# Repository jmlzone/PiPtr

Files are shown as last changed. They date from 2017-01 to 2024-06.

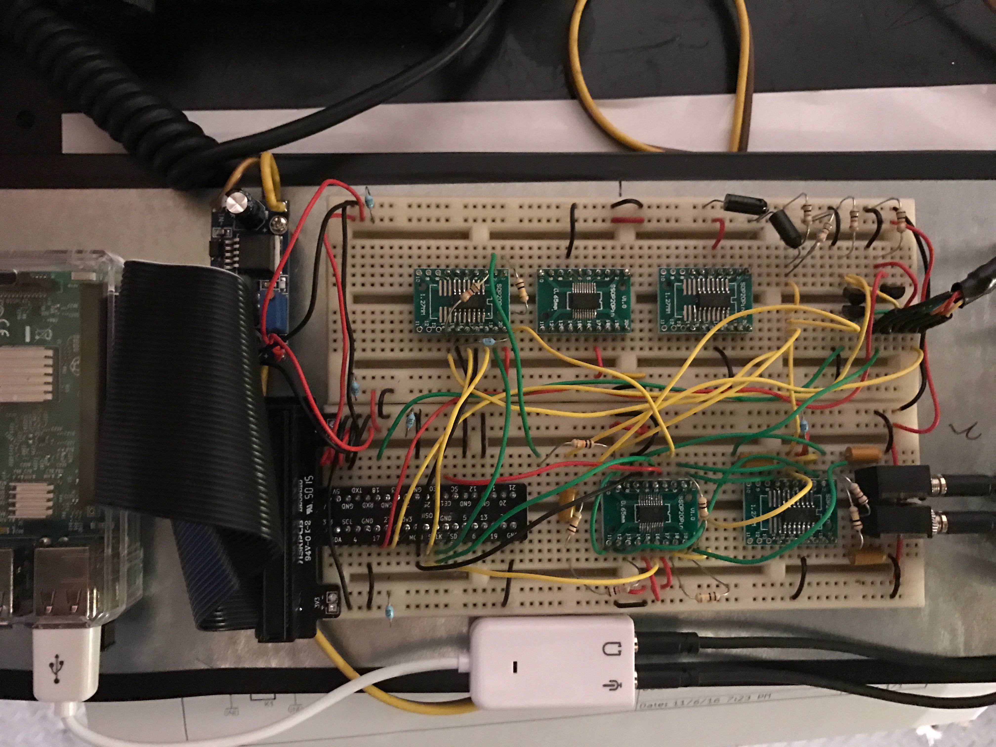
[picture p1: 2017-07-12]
doc/IMG_1390.jpg

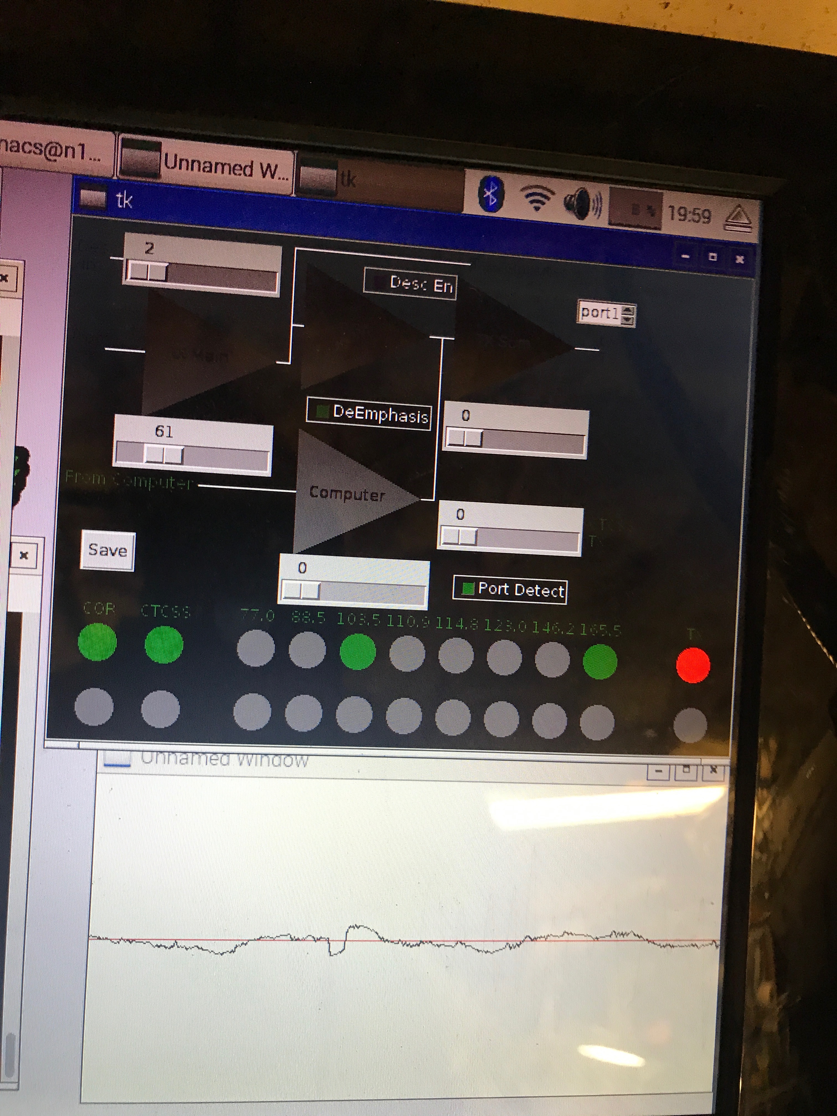
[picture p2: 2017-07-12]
doc/IMG_1817.jpg

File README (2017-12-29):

This is the README for the Rasberry Pi Ham Hadio Repeater Controller
project.  The Goal of this project is to develop an inexpensive
linking repeater controller witha cost of aproximatly $100/port vs
current commerical solutions which are closer to $160/port.

This is an extensable linkable controller with both local and remote
linking.

For information on the mmra network see mmra.org
For information on this project contact jml@jmlzone.com.

For information on setting up this project on a Pi3 please see the Quickstart.txt

Most of the code will be in Python, however some of it is in C.

Eventually there will be good documeation and a bug/enhancement
tracking WIKI or some such thing.

Current state: The test repeater is stable on the air but many many
things are still to be done.

----------------------------------------------------------------------
Mailing lists for the project
  Please join one or more of the groups below.
MMRA-PiPtr-Hardware+subscribe@groups.io
MMRA-PiPtr-Software+subscribe@groups.io
MMRA-PiPtr-Documentation+subscribe@groups.io

----------------------------------------------------------------------

As you know the MMRA maintains a network of 22 repeaters.  A repeater
is basically a receiver, a transmitter and a controller
in-between. While the network generally works, there are some upgrades
we are continually working on.  One of these efforts being led by me,
James N1DDK, is developing a new repeater controller to enhance the
remote controllability, monitoring and adjusting of the
repeaters. Most of the repeater controller in use today are based on
designs over 20 years old. There have been many advances in technology
in the past 20 years. This project is bringing a more modern, more
scalable and more software based and controllable approach based on
mostly standard hardware and using popular modern methods.

 There are some guiding principles to this project:
1) No Jumpers, switches or mechanical pots that can be set incorectly at a site needing a return visit.
2) Open source -- its part of the Ham culture to experiment and share. This will also ensure longevity of the project beyond the initial developers.
3) Better ease of use than similar commercial products.
4) Scaleability and cost per port more effective than the commercial products.
5) Mostly software for simple functions like CTCSS encode / decode, DTMF encode / decode, timers, morse etc.
6) Well documented

Goals
 * Ease of use for users and control operators.
 * Web back end to view status and control linking.
 * Ability to sell hardware as a fundraiser for MMRA.

To this end I have been working mostly solo with some input from K1IW and W1BRI (and some non members) and I have a working prototype on the air on 224.080 as part of a test platform. The next goals will be to make some boards and have further testing and development.

Here is a list of some of the help that is desired:
 * Programming help in C and Python (possibly java/java script for some of the web interface)
 * Schematics design/review for the custom audio board.
 * Documentation help -- there is some basic documentation, but it would be good to have much more on both hardware, software and user guides.
 * Mechanical/sheet metal design for an enclosure, etc
 * Building help, both mechanical and building the initial boards for testing.
 * Testing help using the controller on a bench and trying things before we put them on the air.
 * On the air testing.

Want to learn more?
 There is a git-hub repository for the software, documentation and issue tracking:
https://github.com/jmlzone/PiPtr
There may be a talk about the project at Boxborough!

Even if you don't know anything about software or repeater controllers you can still help! You don't need to know anything to be a documentation volunteer!

Ready to help?
Contact James, n1ddk@mmra.org.

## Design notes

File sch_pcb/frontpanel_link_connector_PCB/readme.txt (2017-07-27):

This directory contains the schematic and PCB for the front panel connector board.  This will be used at the leftmost and rightmost 
boards in a rack chassis to allow interconnecting between chasses

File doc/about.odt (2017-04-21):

PiPtr Documentation.

Rev 0.0 April 14, 2017

James Lee N1DDK

Revision | Date | Who | Description
0.0 | April 14,2017 | James Lee | Initial document

Notes:

Table of Contents

# Introduction

This repeater control project is more than yet another open source ham radio repeater cotroller.

Take a moment to read at least th enext few paragraphs before diving into and of the latter detailed sections.

Also donations are welcome through PayPal to jml@jmlzone.com or through mmra.org.

## Why?

The Minute Man repeater Association (www.mmra.org) maintains a network of over 20 repeaters throughout eastern and metro west Massachusetts. These repeaters are controlled by a variety of different controllers with obscure programming and control methods. While the technical committee for these repeaters has tried to minting a constant model, very few control operators are able to easily configure and maintain the system. When using commercial repeater controllers, the controllers tend to be over $150 per port and have limited expansion capabilities for large sites or are over kill with more ports than needed for a remote site.

Other issues seen on the MMRA network are:

- Difficulties with clock synchronization on the controllers on the network.
- Occasional random behavior from aging EEPROMs, lighting struck hardware and other controller hardware flakiness.
- Lack of source control and documentation for the repeater programming.
- long lag times when network comes up due to cascaded slow controller response.
- Limited internet control

## Goals

- Open source hardware and software for long term wide spread support.
- Cost effective goal of $50 per port.
- Fast and flexible networking
- Extensive internet and non internet control
- Accurate clocks
- Software upgradable.

## Why not?

Why not use open repeater or some of the other open source projects out there?

- The may not be as “open” as the name suggests.
- The may not be designed for linking and some of our other goals.

## Basic Architecture

The basic design is a add on board for a Raspberry Pi 2, 3 or beyond with minimal hardware to provide a full high end repeater controller.

Schematics will be captured in eagle.

Software in Python and C primarily. The 2 most common current programming languages.

There are 2 radio ports per controller and the controllers have side cascading ports to build up in groups of 2. See example network topologies later in the document a site with 7 repeaters, a remote base and 2 link radios would be configured with 5 of these controllers and all linking combinations are possible!

### Custom Hardware

The custom hardware consists of the radio interface and the audio path. It include environmental monitoring to see if you left the lights on in the shelter or if the temperature or humidity is out of bounds. Built in measuring of the 12v repeater power supply and several available user analog channels.

The main rule of thumb is zero jumper and zero mechanical potentiometers. All adjustments are made via software controllable elements.

### Audio

Audio is routed in and out of the computer via standard inexpensive USB sound cards.

- There is an analog audio path for a repeater to stand alone.
- There is an analog audio path for the 2 repeaters on a controller to link.
- There are 2 analog audio paths for controller to controller linking.
- Additionally since the audio goes in and out of the computer, it is possible to do digital audio formats and or digital repeater linking all in software. This is TBD and currently beyond the scope of the base project.

### Digital Audio Functions

Base digital audio decoding functions include:

- Touch tone decoding
- Soft CTCSS decoding

Basic Audio sending functions include:

- Morse generation
  - ASCII to morse
  - Any tone frequency (specified in Hertz)
  - Any speed (specified in Words per minute)
  - Any amplitude (specified in arbitrary volume units)
- Tone generation
  - Any simple tone or sequence of tones
  - Specified as groups of three numbers:
    - Tone in Hertz
    - Duration in mili-Seconds
    - Amplitude
  - Delays between beeps are just tones of zero amplitude
- Speech Generation
  - Text to speech using one available open source programs
- Wave file play back

Soft modem capabilities allow nodes at remote sites to form an ad-hoc data network a link radio to allow remote controlling, updating and time synchronization.

## Example Network Topologies

### A Basic Node

The basic topology of a single repeater node is 2 radio ports.

The radio ports may be either full duplex repeaters or link/remote base radios.

There are also 2 link ports to link to other controllers.

Controller link1 link2 Radio 1 Radio 2 Drawing 1: Basic Node

### A Single Repeater

A single repeater is the simplest configuration. The repeater would be connected to radio port 1 or 2. thats all.

Controller Repeater

Drawing 2: A single repeater configuration

### 2 Repeaters

With 2 repeaters a repeater would be connected to each radio port. By default they will be independent

repeaters; however the repeaters are completely independently controllable or easily linkable.

Repeater 1 Repeater 2 Controller

Drawing 3: 2 repeater configuration

### A Repeater and a link radio (or remote base)

A link or remote base is connected similarly to a repeater, except it is used half duplex and tail hangs and messaging on the link or remote base radio is minimized.

Controller Repeater Link Radio

Drawing 4: Single repeater with link

### 2 Repeaters With 2 Link Radios

In this configuration it is possible to group a repeater and link on a single controller like above, or you could put both repeaters on once controller and both link radios on the second controller. In the recommended configuration shown below, the controllers would be configured as follows:

- On the repeater controller
  - Both radio ports configured as repeaters
  - The repeaters can be cross linked by connecting both to link 1, the internal link.
  - Either (or both) repeater can be connected to link 2 or link 3 to use the link radios
- On the link radio controller
  - Both ports configured as Links
  - Link radio 1 configured to link 2
  - Link radio 2 configured to link 1

Controller 2 Controller 1 Repeater 1 Repeater 2 Link Radio 2 Link Radio 1 Link 2 Link 3

Drawing 5: 2 repeaters, 2 controllers and 2 links

### More

The examples shown in this section are just examples. You can have as many controllers connected to each other as you like. Also it is not required to connect all link2’s to link2’s and link 3’s to link 3’s so you can have additional logs and global links as makes sense for your network.

Controller 1 Controller 2

Link Radio 1 Link Radio 2 Repeater 1 Repeater 2 Repeater 3 Repeater 4 Link 2 Link 2 Link 3 Link 3Drawing 6: A bigger configuragtion

Controller n

Remember:

- All radio ports can act as fully independent repeaters.
- Link 1 exists to allow the 2 ports on a controller to link.
- Link 2 and Link 3 are simple connections to physically co-located radios and repeaters.

# Hardware Description

## Radio Port

The radio port comes out on a 10 pin header (only 9 pins are used). This may be cabled with a simple ribbon cable to a 9 pin D connector DE9F to be compatible with radios bailed for an Scom 7330 controller. However there is more capability than a basic Scom controller.

Header Pin | De 9 pin | Function
1 | 1 | Receiver audio
2 | 6 | GND (RX audio)
3 | 2 | COR (logic)
4 | 7 | GND (CTCSS audio)
5 | 3 | CTCSS decode (logic / or discriminator audio)
6 | 8 | Transmitter (CTCSS audio or logic control)
7 | 4 | PTT
8 | 9 | GND (Transmit Audio)
9 | 5 | Transmitter audio
10 | NA | Physical key

### Receiver Logic Connections

The COR and CTCSS inputs can be logic level from 1.6V to 30V for a logic ‘1’ and less than 0.6V for a logic ‘0’ The polarity of the logic does not matter since it can be inverted in the configuration. There are no jumpers to set. If they are not used, the pins can be left un-connected.

### CTCSS

If a hardware CTCSS decoder is not part of the radio hardware it is not needed. Discriminator audio may be brought in on the CTCSS pin or of the receiver does not high pass the audio to filter out the CTCSS tones, the CTCSS Tones will be decoded off the receive audio.

### DTMF

The DTMF tone will be decoded off the discriminator or receive audio, which every was used for the CTCSS.

## Transmitter Connections

### PTT

The push to talk output is an open drain control camaple of sinking 200mA at up to 35 volts.

### CTCSS

The CTCSS output can be either an open drain output or an audio output under software contol.

## Environmental Monitor

The environmental monitor consists of a DHT22 (AM2302) temperature and relative humidity sensor and a light depending resistor (CDS cell). These are both mounted to the board and are monitored periodically by the software.

## User IO

The user IO convicts of TBD logic IO pins and TBD analog input pins. The digital pins can be configured for input or output. The analog pins are by default scaled for 0-25 volts

## Host Port

The host port is the mapping from physical bus pins on the host board to the functions used on the controller.

PI pin assignments
pin # | Pi Name | Pi Alt | function | Note:
1 | 3.3v
2 | 5v
3 | GPIO2 | SDA1
4 | 5v
5 | GPIO3 | SCL1
6 | gnd
7 | GPIO4 | GPIO_GCLK
8 | GPIO14 | TDX0 | dctcss1
9 | gnd
10 | GPIO15 | RXD0 | dctcss2
11 | GPIO17 | GPIO_GEN0 | cor1
12 | GPIO18 | GPIO_GEN1 | pwm0 | Was Ptt earlier
13 | GPIO27 | GPIO_GEN2 | hwctcss1
14 | gnd
15 | GPIO22 | GPIO_GEN3 | ptt1
16 | GPIO23 | GPIO_GEN4 | COR2
17 | 3.3v
18 | GPIO23 | GPIO_GEN5 | CTCSS2
19 | GP10 | SPI_MOSI
20 | gnd
21 | GPIO9 | SPI_MISO
22 | GPIO25 | GPIO_GEN6 | ptt2
23 | GPIO11 | SPI_SCLK
24 | GPIO8 | SPI_CE0_N | SPIG2A
25 | gnd
26 | GPIO7 | SPI_CE1_N | SPIG1
27 | ID_SD
28 | ID_SC
29 | GPIO5 | | SPIA
30 | gnd
31 | GPIO6 | | SPIB
32 | GPIO12 | | SPIC
33 | GPIO13 | | LINK1O
34 | gnd
35 | GPIO19 | | pwm1
36 | GPIO16 | | LINK1C
37 | GPIO37 | | liknc2o
38 | GPIO20 | | link2c
39 | gnd
40 | GPIO21

## I2C bus

There is a 3.3v and 5v shared I2C bus available for expansion such as extra GPIO or specific control functions. The 5V I2C is used on the board for slave addresses: so be careful when adding I2C devices.

## Audio Path Theory of Operation

The incoming audio from the receiver is gained up to be 2V peak to peak coming out of the input buffer. When the main audio is used to drive the soft CTCSS and DTMF decoder, there is a fixed attenuation before this level goes out to the computer, This path can be enabled for initial tune up. Software can be used to monitor this point and help adjust the base receiver level.

From the first level receiver input amplifier the signal level is adjustable to any of the 4 link / mixing busses:

- Link 0, local transmitter only.
- Link 1, either transmitter on this node.
- Link 2, an external link
- Link 3, an external link

The link connection and level are controllable via the software controllable potentiometers. Remember that these soft pots also contain switches and the connection to any of these points is disconnected when not in use.

From the link / mixing busses the signal can be picked up by the programmable gain amplifier which has the ability to select any of the 4 sources as its input. If needed gain can be applied here. This output is then mixed with the sound card output buffer before being sent to the transmitter.

From the USB sound card a programmable gain buffer is used to buffer the sound card output to a fixed impedance. This is then mixed with the receive audio from the programmable gain amplifier above.

The transmit audio is a programmable gain buffer which gets the sum of the selected receive audio and the sound card audio.

When discriminator output is used to drive the CTCSS decoder the buffer from eh CTCSS input is buffered to 2V peak to peak and then attenuated before going out to the USB sound card to be used for the soft CTCSS and DTMF decoding.

All the audio circuits are reference to Vref at 2.5 V and supplied from the 5V supply. The 5V analog supply is just a low pass filter version of the 5V supply bucked from 12V supply.

# Quick Start Guide

Since we are currently in “developer mode” it is highly recommended that you have a HDMI monitor and USB keyboard and mouse on your Raspberry Pi and to have your Raspberry Pi on the internet, hardwired or wireless with a high speed data connection for all the software you will install.

## Install Rasbian.

Jessie is what is being used for the initial bring up. Follow the directions one the raspberry pi web site to install the base operating system.

## Post configure your raspberry pi

Run raspi-config:

1. Set your host name to be unique; Suggestion callsign_frequency: ie n1ddk_224_080
2. Enable spi (under advanced options)
3. Strongly suggested to set your internationalization options, timezone, keyboard, etc.

## Update your Raspberry Pi

sudo aptget-update

sudo aptget-upgrade

## Install supplemental packages

sudo apt-get install -y python-dev

sudo apt-get install -y espeak

## Bring in the git repository for the repeater control software

git clone …

## give it a test spin

sudo python/main.py

# Software Description

## Configuration XML

The config.xml file contains a template and sample configuration for the controller. Although intended to be machine readable it is generally human readable. The Controller contains a GUI with limited capability to dump the file, however a full functioning editor for this file could be developed.

Once the host name four your RaspberryPi node is set, a node specific version of this file will be loaded (and saved) using the naming rules defined below.

## File Loading and Overriding

The Python and config files are by default in the python directory. Once your host name is set to something other then the default of ‘raspberrypi’ if a directory matching your host name exists files in that directory will have precedence over files in the python directory. Additionally the file <hostname>/<hostname>.xml (where <hostname> is replaced with your host name) will be the highest precedence configuration file and will be the file name used when saved from the GUI.

If you want to override any of the python files with your user code, you can copy the file from the python directory and edit it and place it in the <hostname> directory. However note that if you get an update to the code, it will not be reflected in your edited files.

## Primary C programs

These program reside in the bin directory; C source, headers and makefile are provided in the c directory. They are called and run directly from the main python code; however you can trunthem and test them form the command line if you wish to experiment with them.

### multimon

Multimon was written in 1996 by Thomas Sailer (sailer@ife.ee.ethz.ch, hb9jnx@hb9w.che.eu) and released with GNU general public license. It has been significantly enhanced by James Lee N1DDK in 2016 and 2017 to include ALSA input and CTCSS decoding. Additionally the DTMF decoding has been enhanced to decode larger windows for less glitching and a ‘mute’ output was added to the DTMF decoding.

Multimon includes the capability to decode many other formats such as bell202 for APRS, those capabilities exist within the program but are not currently used by the repeater controller.

### mout

mout is the Morse output routine based on ascii to morse code written by James Lee (KA1KUB in 1983) and ported to C in 2016 and added ALSA output in 2017 by James Lee N1DDK. This code take a command line of exactly 5 arguments:

mout <device> <wpm> <freq> <amplitude> <message>

i.e.:

mout sysdefault:CARD=Device 22 660 1000 "this is a test "

### tout

Tout is the general purpose tone generator. It take inputs in sets of 3 and generates one or more tones in a sequence.

tout <device> <freq> <amplitude> <duration> [<freq> <amplitude> <duration>...]

i.e.:

tout sysdefault:CARD=Device 660 1000 100

tout sysdefault:CARD=Device 660 1000 100 100 0 10 440 900 48

## System Executables

### aplay

Aplay is the ALSA play file utility used to play wave files. It is called (from the system) by the controller code when a wave file is needed to be played.

### espeak

Espeak which was one of the additional packages you needed to load is a text to speech routine which can be used in messaging and is used int he talking clock announcements.

## Python Files

### main.py

As the name describes this the the main entry and launch point for the code. It brings in the other files and instantiates the 2 repeater ports, 2 command queues the GUI and (TBD other network control ports)

Once all the objects are instantiated, it called “load XML” to read in the configuration file. Next it starts threads for the 2 ports and the 2 command processors and the GUI.

### radioPort.py

This file has the place holders for all the configurable items on each radio port. It defines the RX and TX classes and the radioPort class. The radioPort creates multiple timers and instantiates the RX and TX classes and the FSM for each port.

### rptfsm.py

This file is the state machine that controls the behavior of a repeater or link. it is separated from the radioPort file since it is likely to undergo significant enhancement.

### cmd.py

This file houses both the command look up table (touch tome codes) for both ports and the code that is executed when a command is entered. It is likely to be greatly enhanced, as well as customized by for each repeater.

# Repeater Control Flow

## state machines

## timers

## command flow

## queues

### Example of Queuable “messages”

### Altername Messages

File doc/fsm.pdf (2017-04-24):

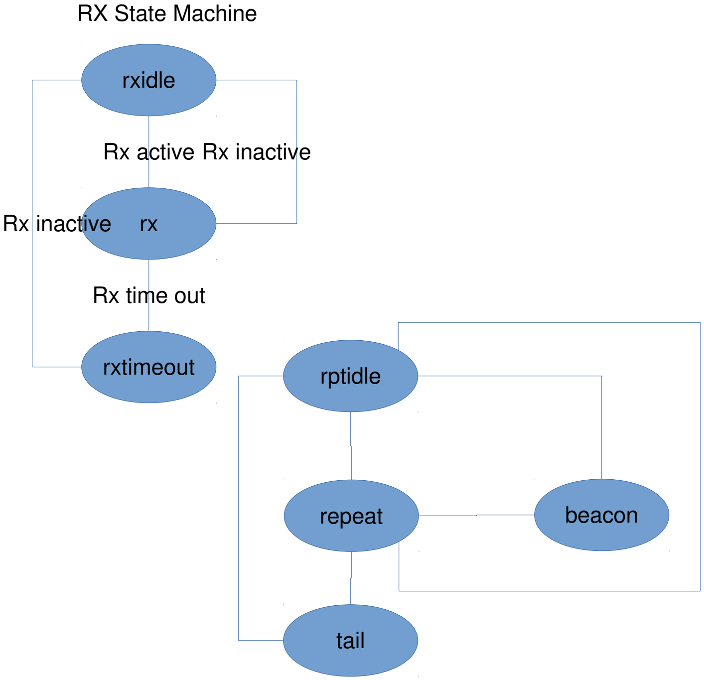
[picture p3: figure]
rxidle; rxtimeout; Rx active; Rx time out; Rx inactive; RX State Machine; rptidle; repeat; tail; beacon

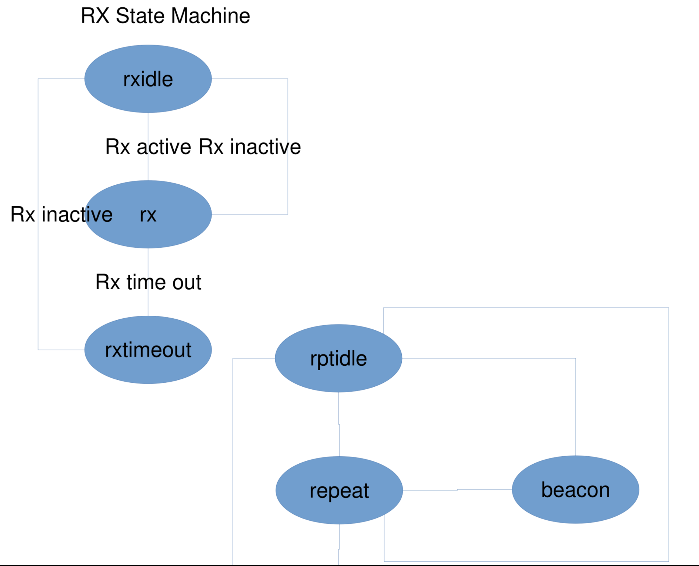
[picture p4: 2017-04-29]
doc/fsm.png

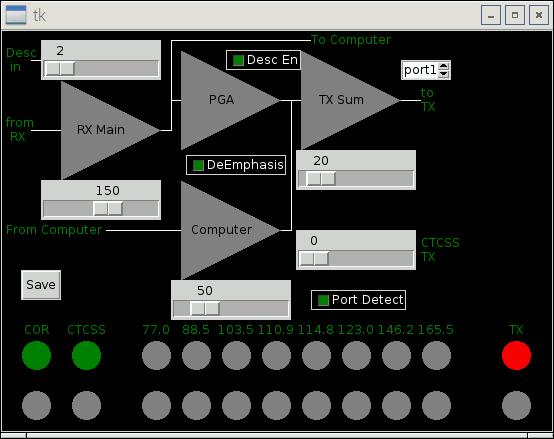
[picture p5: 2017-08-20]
doc/piptrgui.jpg

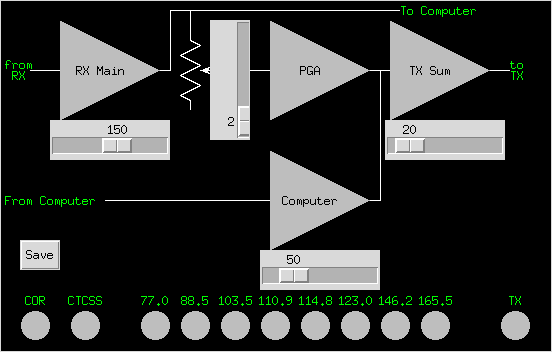
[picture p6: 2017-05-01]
web/ctrl_panel.png

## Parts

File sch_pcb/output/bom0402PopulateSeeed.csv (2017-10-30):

Designator | Manufacturer Part Number | Quantity
C212,C412 | CC0402KRX7R8BB392 | 2
C209,C210,C409,C410 | GRM155R71C273KA01D | 4
C107,C112,C111,C104,C101,C205,C222,C220,C207,C202,C215,C304,C306,C307,C303,C313,C310,C309,C314,C315,C316,C317,C318,C321,C320,C326,C405,C422,C420,C407,C402,C415,C504,C508,C502,C506,C521,C522,C530,C531,C543,C536 | 302010024 | 42
C102,C213,C203,C211,C219,C217,C226,C227,C228,C229,C230,C231,C413,C403,C411,C419,C417,C426,C427,C428,C429,C430,C431 | 302010012 | 23
C214,C223,C414,C423,C512,C510,C511,C509,C527,C528,C542,C541,C540 | 302010053 | 13
C319,C322,C323,C324,C325 | 302010178 | 5
C525,C526,C524,C523 | 302010027 | 4
C106,C103,C206,C201,C204,C225,C221,C208,C305,C312,C311,C308,C406,C401,C404,C425,C421,C408,C503,C507,C514,C520,C519,C518,C501,C505,C513,C517,C516,C515,C529,C532,C539,C534,C538,C537,C535,C533 | 302010019 | 38
J501 | 320010000 | 1
Q102,Q101,Q105,Q103,Q104,Q202,Q201,Q203,Q402,Q401,Q403 | 305030000 | 11
Q501 | 305030026 | 1
R504,R506,R503,R505,R507,R508,R519,R520 | 301010052 | 8
R118,R115,R207,R234,R211,R329,R330,R331,R407,R434,R411,R515,R516,R523 | RC0402FR-0733RL | 14
R124,R324 | 301010028 | 2
R235,R435 | RC0402JR-07680RL | 2
R108,R224,R210,R201,R205,R232,R228,R236,R237,R240,R327,R424,R410,R401,R405,R432,R428,R436,R437,R440 | 301010033 | 20
R112,R113,R109,R102,R101,R225,R206,R221,R222,R233,R229,R209,R227,R244,R301,R309,R323,R319,R318,R317,R316,R315,R425,R406,R421,R422,R433,R429,R409,R427,R444,R518 | 301010004 | 32
R214,R328,R414 | RC0402FR-0713K3L | 3
R509,R510,R511,R512,R501,R513,R517,R521,R522 | RC0402JR-0715KL | 9
R123,R103,R117,R213,R202,R203,R208,R230,R239,R238,R322,R302,R413,R402,R403,R408,R430,R439,R438 | 301010006 | 19
R514,R502 | 301010001 | 2
R223,R423 | RC0402JR-07200KL | 2
R106,R220,R231,R243,R241,R242,R420,R431,R443,R441,R442 | RC0402JR-0720KL | 11
R217,R417 | RC0402JR-0727KL | 2
R120,R104,R105,R110,R111,R107,R114,R212,R215,R219,R226,R308,R412,R415,R419,R426 | RC0402FR-072K2L | 16
R122,R116,R204,R404 | RC0402FR-073K3L | 4
R216,R218,R416,R418 | RC0402JR-0751KL | 4
R321,R310,R311,R312,R313,R314 | RC0402FR-0788K7L | 6
U104 | SN74HCT138DR | 1
U105,U111,U112,U110,U113 | SN74LV1T125DBVR | 5
U109,U206,U202,U203,U406,U402,U403 | SN74LVC1G3157DBVR | 7
U108,U204,U404 | 74LVC4066D,118 | 3
U502,U501,U505 | CM108B | 3
U102,U307,U308 | IP4234CZ6,125 | 3
U305 | MCP1700T-2502E/MB | 1
U504 | MCP1700T-3302E/MB | 1
U101,U208,U408 | MCP23008-E/SS | 3
U301 | MCP23017-E/SO | 1
U304 | MCP3008-I/SL | 1
U103,U107 | MCP4351-103E/ST | 2
U106,U201,U205,U401,U405 | MCP6004-I/SL | 5
U207,U407 | MCP6S26-I/SL | 2
U503 | TUSB2036VFR | 1
Y501 | ABLS-6.000MHZ-D-T | 1

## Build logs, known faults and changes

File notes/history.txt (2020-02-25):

    1  uptime
    2  ls /dev/usb
    3  ls /dev/usb/hiddev0 
    4  sudo reboot
    5  echo $AUDIODEV
    6  ls /dev/dsp
    7  aplay -1
    8  aplay -l
    9  ls /dev
   10  man aplay
   11  sudo apt-get update
   12  sudo apt-get upgrade
   13  sudo raspi-config
   14  exit
   15  which git
   16  pwd
   17  cd python
   18  ls
   19  git clone git://github.com/swharden/Python-GUI-examples
   20  ls
   21  cd Python-GUI-examples/
   22  ls
   23  cd 2016-07-37_qt_audio_monitor/
   24  ls
   25  python go.py 
   26  sudo apt-get install PyQt4
   27  hg clone https://www.riverbankcomputing.com/hg/sip
   28  which hg
   29  pip3 install SIP
   30  wget https://sourceforge.net/projects/pyqt/files/sip/sip-4.18.1/sip-4.18.1.tar.gz
   31  ls
   32  tar tfz sip-4.18.1.tar.gz 
   33  tar xfz sip-4.18.1.tar.gz
   34  cd sip-4.18.1/
   35  ls
   36  more README 
   37  python build.py prepare
   38  ls
   39  more README 
   40  ls
   41  more configure.py 
   42  python configure.py -help
   43  sudo python configure.py
   44  ls -ltr
   45  sudo make
   46  ls
   47  more Makefile 
   48  make 
   49  pwd
   50  cd ..
   51  wget http://sourceforge.net/projects/pyqt/files/PyQt4/PyQt-4.11.4/PyQt-x11-gpl-4.11.4.tar.gz
   52  ls
   53  ls PyQt-x11-gpl-4.11.4.tar.gz 
   54  tar tfz PyQt-x11-gpl-4.11.4.tar.gz 
   55  ls
   56  cd ../
   57  ls
   58  cd 2016-07-37_qt_audio_monitor/
   59  ls
   60  more ui_main.py 
   61  ls
   62  more SWHear.py 
   63  sudo apt-get install python-dev
   64  sudo apt-get install -y python-dev --fix-missing
   65  sudo apt-get update
   66  sudo apt-get install -y python-dev --fix-missing
   67  pwd
   68  ls
   69  cd sip-4.18.1/
   70  ls
   71  make
   72  make clean
   73  make
   74  sudo make installl
   75  sudo make install
   76  ls
   77  cd ../
   78  ls
   79  tar xfz PyQt-x11-gpl-4.11.4.tar.gz 
   80  cd PyQt-x11-gpl-4.11.4
   81  ls
   82  more README 
   83  python configure-ng.py
   84  sudo apt-get install qt
   85  sudo apt-get install qt4-dev-tools
   86  python configure-ng.py
   87  history
   88  ls
   89  more README 
   90  make 
   91  sudo make install
   92  ls
   93  cd ../
   94  ls
   95  python go.py 
   96  history
   97  python go.py 
   98  git clone https://github.com/pyqtgraph/pyqtgraph
   99  ls
  100  cd pyqtgraph/
  101  ls
  102  python setup.py
  103  python setup.py -help
  104  python setup.py --help
  105  python setup.py build
  106  sudo python setup.py install
  107  cd ../
  108  ls
  109  python go.py
  110  hi
  111  history
  112  python go.py
  113  git clone http://people.csail.mit.edu/hubert/git/pyaudio.git
  114  cd pyaudio/
  115  ls
  116  sudo apt-get install python-pyaudio
  117  python go.py
  118  pwd
  119  cd ../
  120  python go.py
  121  history
  122  sudo apt-get install python-matlibplot
  123  sudo apt-get install matlibplot
  124  sudo apt-get install matplotlib
  125  sudo apt-get install python-matplotlib
  126  python go.py
  127  sudo apt-get install python-scipy
  128  python go.py
  129  xterm &
  130  emacs 
  131  cd c
  132  ls
  133  cd multimon/
  134  ls
  135  ./bin-armv7l/multimon 
  136  ./bin-armv7l/multimon scope
  137  ls
  138  more unixinput.c 
  139  ls
  140  more demod_afsk12.c 
  141  ls
  142  more demod_dtmf.c 
  143  ls
  144  more mkcostab.c 
  145  ls
  146  ls bin-armv7l/mkcostab
  147  bin-armv7l/mkcostab
  148  ls -ltr
  149  more costab.c
  150  more costabf.c 
  151  more costabi.c 
  152  ls
  153  emacs Makefile
  154  bg
  155  ls
  156  more gen.c 
  157  ls
  158  more xdisplay.c 
  159  ls
  160  more multimon.h 
  161  cd python
  162  ls
  163  cd Python-GUI-examples/
  164  ls
  165  cd 2016-07-37_qt_audio_monitor/
  166  puthon go.py 
  167  python go.py 
  168  pwd
  169  cd python
  170  ls
  171  pwd
  172  ls
  173  ls ../
  174  mv ../gistfile1.py .
  175  more .
  176  more gistfile1.py 
  177  which python
  178  python gistfile1.py 
  179  python my_goertzel.py 
  180  python
  181  cd pythin
  182  cd python
  183  ls
  184  mroe my_goertzel.py 
  185  more my_goertzel.py 
  186  python my_goertzel.py
  187  ls ~/.ssh
  188  mkdir ~/.ssh
  189  ifconfig | more
  190  ls -l ~/.ssh
  191  python my_goertzel.py
  192  python setup.py build_ext -- inplace
  193  python setup.py build_ext --inplace
  194  pip instal Cython
  195  sudo pip install Cython
  196  python setup.py build_ext --inplace
  197  ls -ltr
  198  python my_goertzel.py
  199  cd ../
  200  mkdir c
  201  cd d
  202  cd c
  203  ls
  204  cc -o alsa_listen alsa_listen.c
  205  ls /usr/lib/alsa
  206  ls /usr/lib
  207  sudo apt-get install libasound2-dev
  208  sudo apt-get -y install libasound2-dev
  209  cc -o alsa_listen alsa_listen.c
  210  cc -o alsa_listen alsa_listen.c -lasound
  211  ls
  212  ./alsa_listen 
  213  which xgps
  214  sudo apt-get install gpsd gpsd-clients python-gps
  215  sudo lsusb
  216  ls /dev/tty*
  217  sudo gpsd /dev/ttyUSB0 -F /var/run/gpsd.sock
  218  cgps -s
  219  xgps
  220  sudo lsusb
  221  cgps
  222  sudo reboot
  223  sudo lsusb
  224  ls /dev/tty*
  225  man gpsd
  226  gpsd /dev/ttyUSB0
  227  cgps
  228  mau gpsd
  229  man gpsd
  230  gpsd /dev/ttyUSB0 -D2
  231  ps -auxww | grep gps
  232  kill 1046
  233  sudo kill 1046
  234  ps -auxww | grep gps
  235  man gpsd
  236  gpsd -D 2 -N /dev/ttyUSB0 
  237  minicom /dev/ttyUSB0 
  238  sudo apt-get install -Y minicom
  239  sudo apt-get install -y minicom
  240  minicom
  241  sudo lsusb
  242  ls /dev/usb
  243  ls /dev/usb/hiddev0 
  244  ls /dev/tty*
  245  gpsd -D 2 -N /dev/ttyUSB0 
  246  sudu shutdown -h now
  247  sudo shutdown -h now
  248  minicom /dev/ttyUSB0 
  249  sudo minicom /dev/ttyUSB0 
  250  ls -l /dev/ttyUSB0 
  251  sudo chmod a+rw /dev/ttyUSB0
  252  ls -l /dev/ttyUSB0 
  253  echo hello >> /dev/ttyUSB0
  254  man stty
  255  more .asoundrc
  256  more /usr/share/alsa/alsa.conf
  257  more /etc/asound.conf
  258  aplay /usr/share/sounds/GNUstep/Ping.wav 
  259  aplay /usr/share/sounds/GNUstep/Ping.wav  -D sysdefault:CARD=Device
  260  aplay /usr/share/sounds/GNUstep/Pop.wav  -D sysdefault:CARD=Device
  261  aplay /usr/share/sounds/GNUstep/Pop.wav
  262  export ALSA_PCM_CARD sysdefault:CARD=Device
  263  export ALSA_PCM_CARD=sysdefault:CARD=Device
  264  aplay /usr/share/sounds/GNUstep/Pop.wav
  265  export ALSA_PCM_CARD=hw:1,0
  266  aplay /usr/share/sounds/GNUstep/Pop.wav
  267  export ALSA_PCM_CARD=
  268  aplay /usr/share/sounds/GNUstep/Pop.wav
  269  export ALSA_CARD=sysdefault:CARD=Device
  270  aplay /usr/share/sounds/GNUstep/Pop.wav
  271  export ALSA_CARD=
  272  aplay /usr/share/sounds/GNUstep/Pop.wav
  273  export ALSA_CARD=hw:1,0
  274  aplay /usr/share/sounds/GNUstep/Pop.wav
  275  export ALSA_CARD=Device
  276  aplay /usr/share/sounds/GNUstep/Pop.wav
  277  say hello
  278  export ALSA_PCM_CARD=Device
  279  say hello
  280  aplay /usr/share/sounds/GNUstep/Pop.wav
  281  man say
  282  man GSSpeechServer
  283  man GNUstep
  284  ps | grep GS
  285  ps | grep speech
  286  say hello
  287  man GSTest
  288  GSTest
  289  say hello this is a much longert test he there boys
  290  which GSSpeechServer
  291  GSSpeechServer --help
  292  ps | grep GSSpeechServer
  293  ps auxww | grep GSSpeechServer
  294  date
  295  kill 21169
  296  ps auxww | grep GSSpeechServer
  297  say hello this is a much longert test he there boys
  298  man say
  299  sudo apt-get install espeak
  300  espeak hello world
  301  espeak "hello world"
  302  espeak -v pt "hello world"
  303  man espeak
  304  espeak -v
  305  espeak --voices
  306  espeak -v "hello world"
  307  espeak -v en "hello world"
  308  espeak -v en-us "hello world"
  309  say "hello world"
  310  history | grep export
  311  hisotry
  312  history
  313  or say hello this is a much longert test he there boys
  314  say hello this is a much longert test he there boys
  315  say hello this is a much longert test hey there boys
  316  say hello this is a much longert test, hey there boys
  317  say hello this is a much longert test. hey there boys
  318  say hello this is a much longert test. Hey there boys!
  319  espeak hello this is a much longert test. Hey there boys!
  320  espeak "hello this is a much longert test. Hey there boys!"
  321  espeak -v en-us "hello this is a much longert test. Hey there boys!"
  322  man espeak
  323  say hello
  324  set ALSA_CARD sysdefault:CARD=Device_1
  325  say hello
  326  echo $ALSA_CARD
  327  set ALSA_CARD=sysdefault:CARD=Device_1
  328  echo $ALSA_CARD
  329  set ALSA_CARD "sysdefault:CARD=Device_1"
  330  echo $ALSA_CARD
  331  ALSA_CARD="sysdefault:CARD=Device_1"
  332  echo $ALSA_CARD
  333  say hello
  334  aplay -l
  335  ALSA_CARD=Device_1
  336  say hello
  337  aplay -vv -D sysdefault:CARD=Device_1 /usr/share/sounds/GNUstep/*.wav
  338  aplay -vv  /usr/share/sounds/GNUstep/*.wav
  339  more ~/.asoundrc 
  340  aplay -vv  /usr/share/sounds/GNUstep/*.wav
  341  top
  342  which say
  343  say --help
  344  say -h
  345  man say
  346  top
  347  bin-armv7l/multimon sysdefault:CARD=Device -s POCSAG512  -s POCSAG1200 -s POCSAG2400 -s AFSK2400 -s AFSK2400_2 -s HAPN4800 -s FSK9600 -s ZVEI
  348  bin-armv7l/multimon sysdefault:CARD=Device
  349  bin-armv7l/multimon sysdefault:CARD=Device 
  350  bin-armv7l/multimon sysdefault:CARD=Device -s POCSAG512 -s POCSAG1200 -s POCSAG2400 -s AFSK2400 -s AFSK2400_2 -s HAPN4800 -s FSK9600 -s DTMF -s ZVEI -s SCOPE
  351  bin-armv7l/multimon sysdefault:CARD=Device -s POCSAG512 -s POCSAG1200 -s POCSAG2400 -s AFSK2400 -s AFSK2400_2 -s HAPN4800 -s FSK9600 -s DTMF -s ZVEI 
  352  bin-armv7l/multimon sysdefault:CARD=Device -s POCSAG512 -s POCSAG1200 -s POCSAG2400 -s AFSK2400 -s AFSK2400_2 -s HAPN4800 -s FSK9600  -s ZVEI 
  353  bin-armv7l/multimon sysdefault:CARD=Device -s POCSAG512 -s POCSAG1200 -s POCSAG2400 -s AFSK2400 -s AFSK2400_2 -s HAPN4800 -s FSK9600  -s ZVEI -s SCOPE
  354  ls
  355  ls  c
  356  ls -l
  357  cd
  358  cd c
  359  ls
  360  ls -l
  361  ./alsa_listen 
  362  acrecord -l
  363  cd multimon
  364  ls
  365  ls filter
  366  which aplay
  367  ls /usr/bin/a*
  368  arecord -l
  369  ls
  370  cd ../
  371  ls
  372  more alsa_listen.c 
  373  amixer
  374  amixer -l
  375  amixer -c 0
  376  amixer -c 1
  377  amixer -c 2
  378  ls -l /usr/bin/aplay /usr/bin/arecord
  379  ls
  380  cd multimon/
  381  ls
  382  make
  383  grep /dev/dsp *.c *.h
  384  more unixinput.c 
  385  ls /usr/share/sounds
  386  ls /usr/share/sounds/*
  387  aplay -c 1 /usr/share/sounds/GNUstep/Frog.wav 
  388  aplay -c 2 /usr/share/sounds/GNUstep/Frog.wav 
  389  amixer -c 2
  390  amixer -c 1
  391  amixer -help
  392  amixer -c 1 -i
  393  amixer -c 1 scontrols
  394  aplay -c 2 /usr/share/sounds/GNUstep/*.wav
  395  aplay -c 1 /usr/share/sounds/GNUstep/*.wav
  396  aplay -c 0 /usr/share/sounds/GNUstep/*.wav
  397  aplay -c 3 /usr/share/sounds/GNUstep/*.wav
  398  aplay -D 4 /usr/share/sounds/GNUstep/*.wav
  399  aplay -l
  400  aplay -L
  401  aplay -D front:CARD=Device,DEV=0 /usr/share/sounds/GNUstep/*.wav
  402  aplay -D front:CARD=Device_1,DEV=0 /usr/share/sounds/GNUstep/*.wav
  403  aplay -D hw:1,0 /usr/share/sounds/GNUstep/*.wav
  404  aplay -D hw:0,0 /usr/share/sounds/GNUstep/*.wav
  405  aplay -D"front:CARD=Device_1,DEV=0" /usr/share/sounds/GNUstep/*.wav
  406  aplay --device front:CARD=Device,DEV=0 /usr/share/sounds/GNUstep/*.wav
  407  aplay -vv /usr/share/sounds/GNUstep/*.wav
  408  alsamixer
  409  aplay -vv -c 1 /usr/share/sounds/GNUstep/*.wav
  410  aplay -vv -c 9 /usr/share/sounds/GNUstep/*.wav
  411  aplay -vv -D 1 /usr/share/sounds/GNUstep/*.wav
  412  aplay -
  413  aplay -L
  414  aplay -vv -D sysdefault:CARD=Device_1 /usr/share/sounds/GNUstep/*.wav
  415  aplay -L
  416  aplay -vv -D sysdefault:CARD=Device /usr/share/sounds/GNUstep/*.wav
  417  aplay -vv -D sysdefault:CARD=Device_1 /usr/share/sounds/GNUstep/*.wav
  418  aplay -L
  419  hi
  420  history
  421  history | grep cc
  422  cd ../
  423  cc -o alsa_listen alsa_listen.c -lasound
  424  ./alsa_listen 
  425  ./alsa_listen sysdefault:CARD=Device
  426  ./alsa_listen sysdefault:CARD=Device_1
  427  cc -o alsa_listen alsa_listen.c -lasound
  428  ./alsa_listen sysdefault:CARD=Device
  429  ls -ltr
  430  cd multimon/
  431  ls -ltr
  432  moe filter.h
  433  more filter.h
  434  ls
  435  ifconfig
  436  history | grep aplay
  437  aplay -vv -D sysdefault:CARD=Device_1 /usr/share/sounds/GNUstep/*.wav
  438  aplay -vv -D sysdefault:CARD=Device /usr/share/sounds/GNUstep/*.wav
  439  aplay -vv -c hw:1,0 /usr/share/sounds/GNUstep/*.wav
  440  aplay -vv -D hw:1,0 /usr/share/sounds/GNUstep/*.wav
  441  aplay -vv -D hw:0,0 /usr/share/sounds/GNUstep/*.wav
  442  aplay -vv -D hw:1,0 /usr/share/sounds/GNUstep/*.wav
  443  aplay -vv -D hw:2,0 /usr/share/sounds/GNUstep/*.wav
  444  aplay -L
  445  aplay -l
  446  aplay -vv -D hw:2,1 /usr/share/sounds/GNUstep/*.wav
  447  aplay -vv -D hw:1,1 /usr/share/sounds/GNUstep/*.wav
  448  aplay -vv -D hw:1,0 /usr/share/sounds/GNUstep/*.wav
  449  aplay -h
  450  aplay -vv -D hw:1,0 /usr/share/sounds/GNUstep/*.wav
  451  sudo shutdown -h now
  452  pwd
  453  cd ../
  454  ls
  455  emacs alsa_listen.c 
  456  bg
  457  history
  458  ./alsa_listen sysdefault:CARD=Device_1
  459  ./alsa_listen sysdefault:CARD=Device
  460  ls -ltr
  461  gdb ysdefault:CARD=Device
  462  fdb ./alsa_listen sysdefault:CARD=Device
  463  gdb ./alsa_listen sysdefault:CARD=Device
  464  cc -o alsa_listen alsa_listen.c
  465  history | grep cc
  466  cc -o alsa_listen alsa_listen.c -lasound
  467  ./alsa_listen sysdefault:CARD=Device
  468  cc -o alsa_listen alsa_listen.c -lasound
  469  ./alsa_listen sysdefault:CARD=Device
  470  cc -o alsa_listen alsa_listen.c -lasound
  471  ./alsa_listen sysdefault:CARD=Device
  472  ./alsa_listen sysdefault:CARD=ALSA
  473  ./alsa_listen sysdefault:CARD=Device
  474  cc -o alsa_listen alsa_listen.c -lasound
  475  ./alsa_listen sysdefault:CARD=Device
  476  cc -o alsa_listen alsa_listen.c -lasound
  477  ./alsa_listen sysdefault:CARD=Device
  478  pwd
  479  cd multimon/
  480  make
  481  grep input_sound *
  482  make
  483  ls -ltr
  484  ls bin-armv7l/
  485  ls ltr bin-armv7l/
  486  ls -ltr bin-armv7l/
  487  bin-armv7l/multimon 
  488  bin-armv7l/multimon -t sysdefault:CARD=ALSA
  489  bin-armv7l/multimon sysdefault:CARD=ALSA
  490  bin-armv7l/multimon sysdefault:CARD=Device
  491  bin-armv7l/multimon sysdefault:CARD=Device -s 
  492  bin-armv7l/multimon sysdefault:CARD=Device -s POCSAG512  -s POCSAG1200 -s POCSAG2400 -s AFSK2400 -s AFSK2400_2 -s HAPN4800 -s FSK9600
  493  bin-armv7l/multimon sysdefault:CARD=Device -s POCSAG512  -s POCSAG1200 -s POCSAG2400 -s AFSK2400 -s AFSK2400_2 -s HAPN4800 -s FSK9600 -s SCOPE -s ZVIE
  494  bin-armv7l/multimon sysdefault:CARD=Device -s POCSAG512  -s POCSAG1200 -s POCSAG2400 -s AFSK2400 -s AFSK2400_2 -s HAPN4800 -s FSK9600 -s SCOPE -s ZVEI
  495  bin-armv7l/multimon sysdefault:CARD=Device -s POCSAG512  -s POCSAG1200 -s POCSAG2400 -s AFSK2400 -s AFSK2400_2 -s HAPN4800 -s FSK9600 -s ZVEI
  496  make
  497  bin-armv7l/multimon sysdefault:CARD=Device -s POCSAG512  -s POCSAG1200 -s POCSAG2400 -s AFSK2400 -s AFSK2400_2 -s HAPN4800 -s FSK9600 -s ZVEI
  498  make
  499  bin-armv7l/multimon sysdefault:CARD=Device -s POCSAG512  -s POCSAG1200 -s POCSAG2400 -s AFSK2400 -s AFSK2400_2 -s HAPN4800 -s FSK9600 -s ZVEI
  500  bin-armv7l/multimon sysdefault:CARD=Device_1 -s POCSAG512  -s POCSAG1200 -s POCSAG2400 -s AFSK2400 -s AFSK2400_2 -s HAPN4800 -s FSK9600 -s ZVEI
  501  make
  502  bin-armv7l/multimon 
  503  bin-armv7l/multimon -h
  504  bin-armv7l/multimon sysdefault:CARD=Device
  505  bin-armv7l/multimon sysdefault:CARD=Device_1
  506  ls
  507  d python
  508  cd python
  509  ls
  510  cd rpt
  511  ls
  512  ls -ltr
  513  sudo python radio.py 
  514  jobs 
  515  top
  516  jobs
  517  kill %1
  518  ls
  519  ls /usr/share
  520  ls /usr/share/sounds/
  521  ls /usr/share/sounds/GNUstep/
  522  ls
  523  lsc
  524  ls c
  525  pwd
  526  ls
  527  cd ../
  528  ls
  529  cd ../
  530  ls
  531  cd c
  532  ls
  533  which speakertest
  534  which speaker-test
  535  file /usr/bin/speaker-test
  536  more alsa_listen.c
  537  pwd
  538  ls
  539  cd ../
  540  ls
  541  cd python
  542  ls
  543  locate playwav.py
  544  ls
  545  cd rpt
  546  ls
  547  pwd
  548  ls-ltr
  549  ls -ltr
  550  pwd
  551  ls
  552  ls /usr/share/sounds/GNUstep/Tink.wav 
  553  sudo python playwav.py /usr/share/sounds/GNUstep/Tink.wav
  554  sudo python playwav.py /usr/share/sounds/GNUstep/Tink.wav -c Device
  555  sudo python playwav.py /usr/share/sounds/GNUstep/Tink.wav -c Device_1
  556  sudo python playwav.py /usr/share/sounds/GNUstep/Tink.wav -c Device_2
  557  sudo python playwav.py -c Device /usr/share/sounds/GNUstep/Tink.wav
  558  sudo python playwav.py -c Device_2 /usr/share/sounds/GNUstep/Tink.wav
  559  sudo python playwav.py -c Device_1 /usr/share/sounds/GNUstep/Tink.wav
  560  pwd
  561  ls
  562  cd c
  563  ls
  564  cc -o alsaOut alsaOut.c -lasound
  565  more alsa_listen.c
  566  cc -o alsaOut alsaOut.c -lasound
  567  ./alsaOut
  568  cc -o alsaOut alsaOut.c -lasound
  569  ./alsaOut
  570  ./alsaOut CARD=Device
  571  ./alsaOut Device
  572  aplay -l
  573  aplay -L
  574  ./alsaOut sysdefault:CARD=Device
  575  cd c
  576  ls
  577  cc mout.c multimon/costabi.c -lasound -o mout
  578  man strtoint
  579  man str2int
  580  cc mout.c multimon/costabi.c -lasound -o mout
  581  mout sysdefault:CARD=Device 13 440  1000
  582  ls -ltr
  583  ./mout sysdefault:CARD=Device 13 440  1000
  584  ./mout sysdefault:CARD=Device 18 800  1000
  585  ./mout sysdefault:CARD=Device 18 800  100
  586  ./mout sysdefault:CARD=Device 18 800  10000
  587  cc mout.c multimon/costabi.c -lasound -o mout
  588  ./mout sysdefault:CARD=Device 18 800  10000
  589  ./mout sysdefault:CARD=Device 18 660  10000
  590  ./mout sysdefault:CARD=Device 18 660  1000
  591  ./mout sysdefault:CARD=Device 18 660  16500
  592  ./mout sysdefault:CARD=Device 18 660  1000
  593  cc mout.c multimon/costabi.c -lasound -o mout
  594  ./mout sysdefault:CARD=Device 18 660  1000
  595  cc mout.c multimon/costabi.c -lasound -o mout
  596  ./mout sysdefault:CARD=Device 18 660  1000
  597  cc mout.c multimon/costabi.c -lasound -o mout
  598  ./mout sysdefault:CARD=Device 18 660  1000 "de N1ddk/r"
  599  ./mout sysdefault:CARD=Device 18 660  1000 "rrr de N1ddk/r"
  600  ./mout sysdefault:CARD=Device 18 660  1000 "rrr de N1ddk/r "
  601  ./mout sysdefault:CARD=Device 18 660  1000 "de N1ddk/r "
  602  ./mout sysdefault:CARD=Device 22 660  1000 "de N1ddk/r "
  603  cc mout.c multimon/costabi.c -lasound -o mout
  604  ./mout sysdefault:CARD=Device 22 660  1000 "de N1ddk/r "
  605  cc mout.c multimon/costabi.c -lasound -o mout
  606  ./mout sysdefault:CARD=Device 22 660  1000 "de N1ddk/r "
  607  cc mout.c multimon/costabi.c -lasound -o mout
  608  ./mout sysdefault:CARD=Device 22 660  1000 "de N1ddk/r "
  609  ./mout sysdefault:CARD=Device 22 660  1000 "de N1ddk/r " fred
  610  ./mout sysdefault:CARD=Device 22 660  1000 "de N1ddk/r "
  611  ./mout sysdefault:CARD=Device 22 660  1000 "this is a test of the demo repeater system - de N1ddk/r "
  612  ./mout sysdefault:CARD=Device 22 660  32000 "this is a test of the demo repeater system - de N1ddk/r "
  613  ./mout sysdefault:CARD=Device 50 660  32000 "this is a test of the demo repeater system - de N1ddk/r "
  614  ./mout sysdefault:CARD=Device 30 660  32000 "this is a test of the demo repeater system - de N1ddk/r "
  615  ./mout sysdefault:CARD=Device 13 660  32000 "this is a test of the demo repeater system - de N1ddk/r "
  616  cd c
  617  ls
  618  cc mout.c multimon/costabi.c -lasound -o mout
  619  mout sysdefault:CARD=Device 13 440  1000
  620  ./mout sysdefault:CARD=Device 30 660  32000 "this is a test of the demo repeater system - de N1ddk/r "
  621  ./mout sysdefault:CARD=Device 30 660  32000 "N1ddk/r"
  622  ./mout sysdefault:CARD=Device 20 660  32000 "N1ddk/r"
  623  cd ~/python/rpt
  624  ls
  625  lpc stat
  626  cd c
  627  ./mout
  628  ./mout sysdefault:CARD=Device 22 660  1000 "this is a test "
  629  ./mout sysdefault:CARD=Device 22 440  1000 "this is a test "
  630  which espeak
  631  espeak "this is a test"
  632  espeak -D sysdefault:CARD=Device "this is a test"
  633  espeak -h
  634  export ALSA_CARD=Device
  635  espeak "this is a test"
  636  espeak "r5=123"
  637  date
  638  date | espeak
  639  export ALSA_PCM_CARD=Device
  640  date | espeak
  641  man date
  642  date %t
  643  date '%t'
  644  date +format '%t'
  645  date +'%t'
  646  date +%T
  647  date +"the time is %T"
  648  date +"the time is %r"
  649  date +"the time is %r" | espeak
  650  date +"the time is %I %M" | espeak
  651  date +"the time is %I %M %A %B %_d" | espeak
  652  date +"the time is %I %M %p, %A %B %_d" | espeak
  653  date +"its %I %M %p, %A %B %_d" | espeak
  654  date +"its %I %M %p, %A %B %_d" | say
  655  hay hello
  656  say hello
  657  date +"its %I %M %p, %A %B %_d" | say
  658  man say
  659  date +"its %I %M %p, %A %B %_d" | say -f stdin
  660  say `date +"its %I %M %p, %A %B %_d"`
  661  date +"its %I %M %p, %A %B %_d" | espeak
  662  history > history.txt

# get the python3 smbus module and other needed modules
sudo apt-get install -y python3-smbus scons python-dev swig

# to set up the neopixel module
# this one hangs freqauently bad!!!
#cd rpi_ws281x/
#scons
#cd python
#python ./setup.py build
#sudo python3 ./setup.py install
# try this variation
#git clone https://github.com/richardghirst/rpi_ws281x
#edit mailbox.c to change the /tmp to /dev...
#git clone https://github.com/plan44/rpi_ws281x
cd ~
git clone https://github.com/jgarff/rpi_ws281x
cd rpi_ws281x/
scons
cd python
python3 ./setup.py build
sudo python3 ./setup.py install

PCB sources
http://www.basicpcb.com/?utm_source=FACEBOOK&utm_campaign=FB-ADS-VIDEO&utm_medium=ADS
https://www.seeedstudio.com/fusion_pcb.html

 673  sudo apt-get install libasound2-dev
  674  sudo -H pip3 install pyalsaaudio
sudo i2cdetect -y 1

sudo apt-get install -y raspi-gpio

gpio readall
./bin/gpio_alt -p 18 -f 5
./bin/gpio_alt -p 19 -f 5
gpio readall

./bin/multimon sysdefault:CARD=Device -a scope &
./bin/multimon sysdefault:CARD=Device_1 -a scope &
./bin/multimon sysdefault:CARD=Device_2 -a scope &

speaker-test -D sysdefault:CARD=ALSA -t sine -f 1000

cd
git clone https://github.com/adafruit/Adafruit_Python_DHT.git
cd Adafruit_Python_DHT
sudo python3 setup.py install
sudo /etc/init.d/udev restart  -- fixes USB enumeration
https://www.aliexpress.com/item/10Sets-5-7mm-Header-Plate-Bracket-Stud-Bolt-Nut-Nuts-Screw-D-Sub-VGA-DB9-DB15/32721156151.html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,searchweb201602_1_10152_10151_10065_10344_10130_10068_10324_10547_10342_10325_10546_10343_10340_10548_10341_10545_10084_10617_10083_10616_10615_10307_10313_10059_10534_100031_10604_10103_10142,searchweb201603_25,ppcSwitch_3&algo_expid=9d866f43-ca2b-4d7e-9e42-42ccc814278a-0&algo_pvid=9d866f43-ca2b-4d7e-9e42-42ccc814278a&transAbTest=ae803_4&priceBeautifyAB=5

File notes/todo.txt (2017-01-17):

1) (done, untested) signals
  -- interupt and shut down
  -- interupt and go interactive
  import code
code.interact(local=dict(globals(), **locals()))
  -- process command

2) IPC from dtmf and ctcss

3) (Done untested) talking clock
  -- time from python
  -- pass in prefix string
4) State as emun

5) Tail message processing
  -- list of messages
  -- attributes:
    - player
    - is ID
    - interuptable
      -- what to do on interrupt
         -- requeue
	 -- discard
	 - alternate message (ie low id)

6) Command processer ideas

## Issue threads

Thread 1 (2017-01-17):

PL decode enhancements

jmlzone, 2017-01-17:
PL decode needs several enhancements.  (Can be broken into multiple issues)
1) pl tones and levels should be configurable via an init file or command line options.
2)tone unlock should only occur after multiple cycles of missed decode.

drhirsch, 2017-06-30:
This is a subtle yet very important area where OEMs like Motorola distinguished themselves from HT to repeater.
[CTCSS IC details](http://www.repeater-builder.com/micor/m6709-info/m6709-info.html)

Since this is software based, we can get a lot smarter about the environment each repeater is in. Does it suffer from co-channel users on different (or the same) tone? Are most of the signals strong or weak? For weak signals, fading signals, particular dynamic algorithms can be employed far more effective than the choices implemented in hardware squelch ICs.

There is a delay, distinct between different models of radios, for CTCSS code from the repeater. Thus a false negative causes annoying audio dropouts at the user receiver, which should be avoided. The repeater receiver has the ability to know it made the wrong decision *post facto* and this can be used as feedback to learn a better response for each signal. Yes, ML for squlech.

scivision, 2017-06-30:
This is a subtle yet very important area where OEMs like Motorola distinguished themselves from HT to repeater.
[CTCSS IC details](http://www.repeater-builder.com/micor/m6709-info/m6709-info.html)

Since this is software based, we can get a lot smarter about the environment each repeater is in. Does it suffer from co-channel users on different (or the same) tone? Are most of the signals strong or weak? For weak signals, fading signals, particular dynamic algorithms can be employed far more effective than the choices implemented in hardware squelch ICs.

There is a delay, distinct between different models of radios, for CTCSS code from the repeater. Thus a false negative causes annoying audio dropouts at the user receiver, which should be avoided. The repeater receiver has the ability to know it made the wrong decision *post facto* and this can be used as feedback to learn a better response for each signal. Yes, ML for squlech.

jmlzone, 2017-06-30:
FYI it is currently configured to decode 8 tones.  There is a reason behind this, actually several.
1) On some repeaters there may be control operator tones which allow the operator to enter commands without first entering a control op code.
2) We may (do) want to implement some automatic linking.  IE you come in to the repeater with time 1 and its a local repeater.  You use tone 2 and you are link to xxx and you use tome 3 and you are linked to yyy.
3) on our hub repeaters we may accept multiple tones, then the tone on each link can be different.  If we are getting interference on a link, the tone will tell us which link the interference was coming into.

There is some outline of this in the code related to softCtcss in the radioPort RX class.

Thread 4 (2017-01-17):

Calibration code

jmlzone, 2017-01-17:
What should the code to to help with turn up and calibration.
Ideas here.

jmlzone, 2017-06-30:
There should be a "find me" mode at start up after loading the xml, the ports though use the audio path from the onboard pwm's to find which usb audio device they are connected to so if they enumerate differences that are properly associated with the correct port.

Also it should be possible to to a soft AGC to correct people with low or loud audio.

scivision, 2017-06-30:
Yes there are a lot of beautiful things that can be done with the audio, particularly useful for linked systems, especially systems involving internet stations and/or 900 MHz repeaters.

jmlzone, 2018-02-03:
See portDetect.py (stand alone test) and the portDetect code in hwio.py, this starts to send tones from one sound card port to another for detection and can figure out which sound card is on which radio port.  its not perfect yet, but its a start.

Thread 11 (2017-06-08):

time out message is uniqification

jmlzone, 2017-06-08:

jmlzone, 2017-06-08:
the rx time out timer is correct hard code to plat "to" in morse at a fixed frequency and speed.  it is played using the usual tx method so can support morse, voice, wave etc.  it should be parameterized per port and should be held in a rx port attribute to be unique.

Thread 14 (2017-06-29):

remote command line ideas

jmlzone, 2017-06-29:
There is now a rudimentary remote command line on a tcp socket.
it should:
1) Have a save command to write out the config xml
2) be switched form an insecure telnet type connection to a ssh like authentication.
3) I think non stirng like value may have problems and i need the type conversions like in xmlio.
4) The dictionary method used here and the xmlio methods should be resolved and common code moved out to a new class.

What else?

scivision, 2017-06-30:
Python SSH Server (one of many choices) https://github.com/paramiko/paramiko/blob/master/demos/demo_server.py

KB1RD, 2017-07-06:
You could also make a new user and allow login through the built-in SSH service and [change the default login shell.](https://stackoverflow.com/questions/13046192/changing-default-shell-in-linux) This would make it impossible to run commands through bash, but would allow you to run commands through a custom shell, possibly written in Python. Some inter-process communication would be required though to send data back to the main process.

jmlzone, 2018-02-03:
Current PiPtr code opens a TCP port and supports a few basic commands, get and set values, enter "touch tone" commands to either port, say the XML config.  there is currently no security layer.  Anyone wishing to contribute to this please have a look at tcpSocketCmd.py

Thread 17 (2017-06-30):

GUI thoughts.

jmlzone, 2017-06-30:
The Current TkInter gui was proof of concept.  The "status" lets do work properly and are tied into callbacks.
I think it properly disables it self if you are not on the X-Display.
The digram shown of the audio controls represent a prior version of the design and don't match whats in the schematic for structure.
The save button does work and will write out the node (host) specific xml file.
What should probably be done:
 * The circuit should match the schematics for the structure and location of the controls.
 * Call backs from the GUI should actually update the "pot" controls in the data structure (HWIO) and actually write to the hardware.
 * I think a single copy of the graphics will suffice with a way of toggling between port1 and port2.
 * the TkInter interface does not need to be kept if a web based GUI is developed for the adjusting.
 * Of course the status lets could be "public" but the controls should be "control operator" restricted.

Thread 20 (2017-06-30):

Web interface ideas

mark66j, 2017-06-30:
Here are some thoughts about web interfaces for the system. This is written without much knowledge of the code so far so it may not entirely make sense, but anyway:

1) I think each controller should have a simple web interface, maybe only accessible to admins, to show the status of that board and allow changes
2) A central web page could show the entire Minuteman system status (somewhat like the current page, but maybe adding a map view). This would be view-only for the public, but admins would be able to click on a repeater and issue commands.
3) Because of browser security rules, the web page may not be able to send commands directly to the repeaters, so a central server may be needed to do this.
4) I am thinking that each controller could have a web services interface (maybe REST?) for use by this central page.
5) It may be helpful to have a simpler central control page that is easier to use on a smart phone.
6) Authentication is tricky -- connections to each controller would need to be protected, but how to push changes to all devices in the system? RADIUS is the traditional way here but there might be better choices.

jmlzone, 2017-06-30:
There is a need for a consolidated control op system overview where a control up can have a button like link all to hub 1 or link these to hub 2 etc.  This may require some sort of middle server code that then breaks the meta command into commands to each repeater as needed.

However I agree a consolidated system status public view is also great!  Some of this can be hosted on MMRA.org and would be part of MMR specific code, while the generic per repeater code (which could even be hosted on the Pi's them selves) would be more a direct part of the public project.

mark66j, 2017-06-30:
I agree. The public project code could expose a web services API that MMRA would use for the central control system and to provide the status view. Organizations that have multiple repeaters could write their own central control, maybe using the MMRA code as a template.

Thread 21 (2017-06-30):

Raspberry Pi SD card file issues

mark66j, 2017-06-30:
I've been using RPi for some home automation work, and have run into one issue that this project should consider.

Every once in a while a Pi becomes unbootable because of corruption on the SD card. This can happen because of improper shutdown on power loss, but also might result from a lot of writes to the SD card.

Sometimes an fsck will fix the card, but I've had a couple that I couldn't fix. If it can be fixed, there may be some data lost.

In a home setup you can make this less painful by making a backup image of each SD card, including all of the local configuration for the Pi, so that you can just crank out a new SD card if the old one dies.

In a remote setup this is obviously more of an issue.

Some things that I think could be done by MMRA to reduce problems (these wouldn't be mandatory for the public project, as they would increase costs):

1) Explore booting from a USB device. This may still be experimental and might only work on a RPi 3, see this link: https://www.raspberrypi.org/blog/pi-3-booting-part-i-usb-mass-storage-boot/
2) Store all the critical configuration on USB storage, so that if the card goes bad less is lost. Still requires someone to go to the site to swap the SD card.
3) Make sure the PI power has some battery backup, reducing the chance for file corruption.
4) (Probably not realistic) Have a failover Pi for each online one

There are other single-board computers that can boot from SATA drives, but this would drive up the costs a lot and none of these are nearly as standard as the RPi.

n1iic, 2017-07-01:
I have also read about concerns with card failures and have been a little concerned with them myself, but I no longer believe it's as necessary to be alarmed unless it's in use at a remote location and there are gigabytes of writing and erasing on a regular basis.
The pi natively handles wear leveling, and with a high quality card of a large size I think this small project will last a significant amount of time.
This post talks about studies and testing:
https://www.raspberrypi.org/forums/viewtopic.php?f=66&t=142626 and look for a post by levelcrow just past half way.
If there is a great concern, the card could only be used for booting which would last almost indefinitely. Pair that with a small, quality, spinning or SSD usb drive and that would be great.
I do agree with using a UPS, I have had corruption issues from time to time with power being removed without cleanly shutting down.

Jason

jmlzone, 2018-02-03:
I finally managed to corrupt a SD card on the PiPtr test system on my desk, took a hard SW crash  not sure of the root cause.  Thanks for the ideas.  Power was not the issue.

As for the confiruration data its all in the XML file which can be remotely stored, so a fresh image with the "correct host name for the site" is all that needed.

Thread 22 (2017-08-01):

Missing connection problem and a unsafe pull connection

jwspencer, 2017-08-01:
1. R504 and R506 have a floating Pin. They are connected to U503 pins 1 (DPO) and pin 2 (DMO).

2. U503	TUSB2036	Pin 6 is an I/O pin (EEDATA) and should not be tied to +3.3VDC. A software/firmware error could cause the chip to fail.

n1ist, 2017-08-06:
1. R504 and R506 connections are waiting for me to pick a USB connector.  I'll do this when I get closer to finishing up the layout.

2.  I have added the pullup.  When EXTMEM is pulled up, EEDATA/~GANGED is only an input; it's hard-tied on TI's eval board as well.  A pullup will make it safer, however.

Closed 2017-08-06.

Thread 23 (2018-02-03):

R0 Board issues -- Open tracker item to track issue found on the R0 board.

jmlzone, 2018-02-03:
This tracker is to list any hardware issues found on the R0 board.
Please see the related trackers issues for:
 * Things still to be tested on the R0 board.
 * Suggested changes for the R1 board.

Once the root cause or solution for an issue is found please also list it here.
Number issues I#, Root Cause RC#, Solution S#

I1) Digitial pots, power and ground swapped.
VDD = 17 = +5
VSS = 7 = GND.
RC1) Schematic Symbol error
S1) Update before next board spin

I2) R308 and R309 refence voltage divider for ADC.  Placement and values swpapped silk vs schematic.
RC2) Confirmed with Seeed support, they followed the silk screen and not the POS file.
S2) We will either  fix the silk or possibly change to a precision 2.048v reference part.

I3) link connector missing 2v5 for terminating link audio lines.
S3) See ideas for updating this on the next board

I4) De9 connectors are too far from the board edge.

I5) When powered before the software is started, the PTT lines are low.
RC5) I think the BSS138's have a lower V that the 2n7000's used in the hand built prototype.
S5) Add 2.2k pull down resistors on the gates of Q201, Q401, Q105, Q105 PTT's

I6) The Discriminator in pot is working backwards.
RC6) the A and B pins of section B of the digital pot, Pins 8 and 10 are reversed.
pin 10 should be 'A' the high side
Pin 8 should be 'B' the low side.
S6) Correct before next board spin

I7) The front panel pixel and old connectors are inaccessible under the USB connectors. As is the J311 expansion connector.

I8) the polarity of the SPDT soft witches were reversed.
S8) Inverted in software.

jmlzone, 2018-02-04:
I9) Ic20 bus is not accessible on the latest PI3's.
S9) Those external IO's need to be moved for the old and the axiom connectors need to be moved to I2C bus1.

n1ist, 2018-02-05:
I'm guessing "axiom" should be aux_IO.  I'll move them (as well as RTC and OLED).  Would we want to add a switch to allow the Pi to isolate the external connectors if there's a problem?  U108 has two unused switches; I haven't used transmission gates on i2c before but I think it should work.  We could use one of the two GPIOs that are now I2C0 to control it./mike

      From: jmlzone <notifications@github.com>
 To: jmlzone/PiPtr <PiPtr@noreply.github.com>
Cc: Subscribed <subscribed@noreply.github.com>
 Sent: Sunday, February 4, 2018 3:16 PM
 Subject: Re: [jmlzone/PiPtr] R0 Board issues -- Open tracker item to track issue found on the R0 board. (#23)

I9) Ic20 bus is not accessible on the latest PI3's.
S9) Those external IO's need to be moved for the old and the axiom connectors need to be moved to I2C bus1.—
You are receiving this because you are subscribed to this thread.
Reply to this email directly, view it on GitHub, or mute the thread.

jmlzone, 2018-02-05:
I have corrected the typo axiom to aux-io.
I had not thought about isolation.
For testing I have cut the traces to pins 1&6 of ESD protection to the AUX-IO connectors, they run next to each other in a wide open area of the board.  I then wired pins 1&6 to the proper connections on Q101 and Q103 and it looks like I can talk to an external device on the I2c with about 2 feet of wire.

With regards to isolation,  since any user of an external I2C device (me) would need to be sure it all can work, and we already have the ESD isolation, I would think that adding isolation just adds a failure point,  but lets keep it open for discussion before we finish the R1 board.  Right now I face the issue of if I have 2 of my external I2C board (that currently don't have addressability) they would both be on address 0x20 if I had one plugged into each aux port.  I think thats my problem and I need to cut a trace on that board to make some of them have a secondary address.  This would be the case of having a PiPtr with 2 link or remote base radios using my I2C frequency control board.

n1ist, 2018-02-05:
I was more worried about an external fault (ie. mouse shorted the cable) taking out local i2c.  If we use an I2C switch like PCA9540B, we can select which port (if any) is active at one time and therefore could have the same addresses on both ports.  It would even do level translation so the two aux ports could have different rails./mike

      From: jmlzone <notifications@github.com>
 To: jmlzone/PiPtr <PiPtr@noreply.github.com>
Cc: n1ist <n1ist@arrl.net>; Comment <comment@noreply.github.com>
 Sent: Monday, February 5, 2018 10:35 AM
 Subject: Re: [jmlzone/PiPtr] R0 Board issues -- Open tracker item to track issue found on the R0 board. (#23)

I have corrected the typo axiom to aux-io.
I had not thought about isolation.
For testing I have cut the traces to pins 1&6 of ESD protection to the AUX-IO connectors, they run next to each other in a wide open area of the board. I then wired pins 1&6 to the proper connections on Q101 and Q103 and it looks like I can talk to an external device on the I2c with about 2 feet of wire.With regards to isolation, since any user of an external I2C device (me) would need to be sure it all can work, and we already have the ESD isolation, I would think that adding isolation just adds a failure point, but lets keep it open for discussion before we finish the R1 board. Right now I face the issue of if I have 2 of my external I2C board (that currently don't have addressability) they would both be on address 0x20 if I had one plugged into each aux port. I think thats my problem and I need to cut a trace on that board to make some of them have a secondary address. This would be the case of having a PiPtr with 2 link or remote base radios using my I2C frequency control board.—
You are receiving this because you commented.
Reply to this email directly, view it on GitHub, or mute the thread.

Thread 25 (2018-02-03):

Suggested changes for the R1 board

jmlzone, 2018-02-03:
- [ ] 1) Fix the power and ground on the digital pots U103/U107.
[link to issue I1](https://github.com/jmlzone/PiPtr/issues/23)
VDD = 17 = +5
VSS = 7 = GND.

- [ ] 2) Fix the reversed B section of the digital pots.
[link to issue I6](https://github.com/jmlzone/PiPtr/issues/23)
the A and B pins of section B of the digital pot, Pins 8 and 10 are reversed.
pin 10 should be 'A' the high side
Pin 8 should be 'B' the low side.

- [ ] 3) Move the DE9 connectors 3.7mm closer to the edge.
[link to issue I4](https://github.com/jmlzone/PiPtr/issues/23)

- [ ] 4) The link connections [link to issue I3](https://github.com/jmlzone/PiPtr/issues/23)
instead of going from a 6 pin connection to 7 pin connector, lets go to a 2x5 10 pin connector for the links.
outboard | inboard
-------- | -------
link1 c - 1 | 2 - 3.3v through 2.2k
link1 a - 3 | 4 - 2.5v through 2.2 k
and	- 5 | 6 - gnd
link3 a - 7 | 8 - 2.5v through 2.2.k
link3 c - 9 | 10 -	3.3v through 2.2k

*the left edge and right edge connectors are mirrors of each other*

- [ ] 5) I have been thinking about the ADC ref. I am considering a real 2.048v reference part. (just a though at this point)
[link to issue I2](https://github.com/jmlzone/PiPtr/issues/23)

- [ ] 6) add pull downs to keep off the PTT's and link outputs when initially powered
[link to issue I5](https://github.com/jmlzone/PiPtr/issues/23)
Add 2.2k pull down resistors on the gates of Q201, Q401, Q105, Q105

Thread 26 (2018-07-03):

Pi issues with multiple cm108B interfaces

jmlzone, 2018-07-03:
There are a number of issues noted, may need fixing at various levels this is an overall tracker to remember them.
1) If the multiple usb round devices are plugged in (or enabled on our hardware) When the desktop gui stats, there may be a weird noise (if speakers are connected) and then a complete hang.

We work around this by powering up and not enabling our hardware until after the GUI boots.  Not sure if its the desktop audio system, Jack, or HID seeing multiple HID devices.

2) Although all the firmware addresses each device uniquely, there does appear to be times when there is "cross talk" when 2 different devices are trying to send sounds to two different ports.

In general it looks like the linux usb audio sub system does not do great with multiple usb sound devices trying to be used uniquely on unique threads.

jmlzone, 2018-07-03:
Weirdness was particularly noted with speech synthesis which has a "jack" layer.  Maybe do a local rebuilt of espeak-ng with only alsa drivers.

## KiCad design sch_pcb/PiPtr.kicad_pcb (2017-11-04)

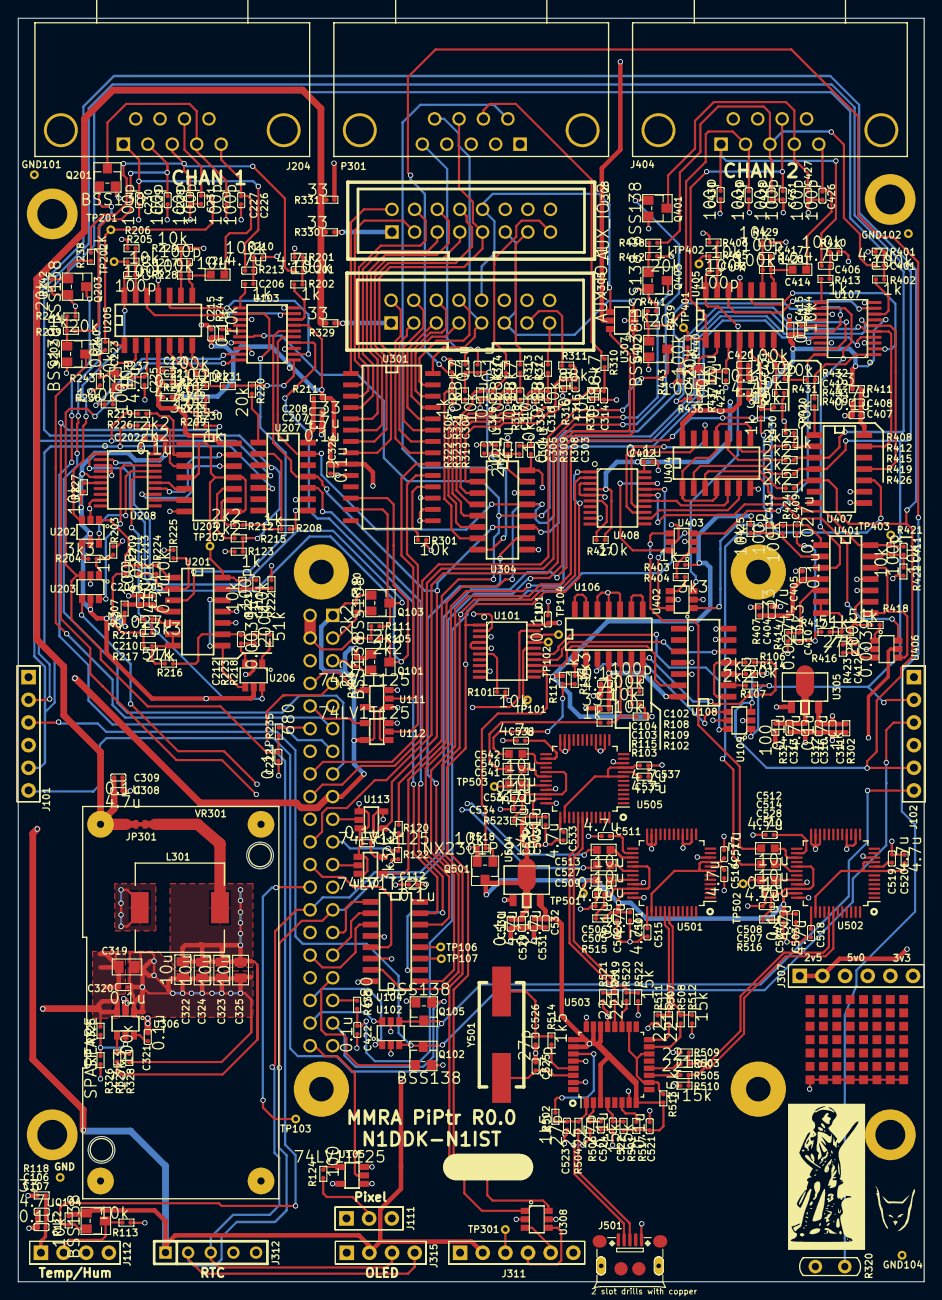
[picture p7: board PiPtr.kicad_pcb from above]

Board: 4 copper layers, 101.6 x 141.7 mm, 388 parts (1 on the bottom side), 297 nets.

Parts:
C101, C104, C107, C111, C112, C202, C205, C207, C215, C220, C222, C303, C304, C306, C307, C309, C310, C313, C314, C315, C316, C317, C318, C320, C321, C326, C402, C405, C407, C415, C420, C422, C502, C504, C506, C508, C521, C522, C530, C531, C536, C543: 0.1u; OPL_C0402
C102, C203, C211, C213, C217, C219, C226, C227, C228, C229, C230, C231, C403, C411, C413, C417, C419, C426, C427, C428, C429, C430, C431: 100p; OPL_C0402
C103, C106, C201, C204, C206, C208, C221, C225, C305, C308, C311, C312, C401, C404, C406, C408, C421, C425, C501, C503, C505, C507, C513, C514, C515, C516, C517, C518, C519, C520, C529, C532, C533, C534, C535, C537, C538, C539: 4.7u; OPL_C0402
C209, C210, C409, C410: 0.027u; OPL_C0402
C212, C412: 0.0039u; OPL_C0402
C214, C223, C414, C423, C509, C510, C511, C512, C527, C528, C540, C541, C542: 10u; OPL_C0603
C319: 10u 25V; OPL_C0805
C322, C323, C324, C325: 10u; OPL_C0805
C523, C524, C525, C526: 27p; OPL_C0402
GND101, GND102, GND103, GND104: TESTPOINT; Wire_28AWG
J101: GLOBAL_LINK_LEFT; OPL_H6-2.54
J102: GLOBAL_LINK_RIGHT; OPL_H6-2.54
J107: RASPBERRY_PI; RaspberryPi2x20
J111: FP_PIXEL; OPL_H3-2.54
J112: AM2302; OPL_H4-2.54
J204, J404: DE9F; DE9F_Right_Angle
J305: AUX_IO_1; RibbonHeader2x8
J307: SPARE; OPL_H6-2.54
J308: AUX_IO_2; RibbonHeader2x8
J311: I2C1_5V; OPL_H6-2.54
J312: RTC; SIL-5
J315: OLED_SSD1306; OPL_H4-2.54
J501: MicroUSB; OPL_MICRO-USB5+4P-SMD-0.65-B
JP301: 5V_switcher_connect; JUMPER_2PIN_CUTTABLE
L301: 10uH; Inductor_Wurth_7447714100
LOGO301: MOUNTING_HOLE; BOBCAT_LOGO
LOGO302: MOUNTING_HOLE; mmra_logo
MTG301, MTG302, MTG303, MTG304: MOUNTING_HOLE; MTG_4_40
P301: Chassis; DE9M_Right_Angle
PROTO301: MOUNTING_HOLE; SMD_proto_area
Q101, Q102, Q103, Q104, Q105, Q201, Q202, Q203, Q401, Q402, Q403: BSS138; OPL_SOT-23
Q501: NX2301P,215; OPL_SOT-23
R101, R102, R109, R112, R113, R206, R209, R221, R222, R225, R227, R229, R233, R244, R301, R309, R315, R316, R317, R318, R319, R323, R406, R409, R421, R422, R425, R427, R429, R433, R444, R518: 10k; OPL_R0402
R103, R117, R123, R202, R203, R208, R213, R230, R238, R239, R302, R322, R402, R403, R408, R413, R430, R438, R439: 1k; OPL_R0402
R104, R105, R107, R110, R111, R114, R120, R212, R215, R219, R226, R308, R412, R415, R419, R426: 2k2; OPL_R0402
R106, R220, R231, R241, R242, R243, R420, R431, R441, R442, R443: 20k; OPL_R0402
R108, R201, R205, R210, R224, R228, R232, R236, R237, R240, R327, R401, R405, R410, R424, R428, R432, R436, R437, R440: 100k; OPL_R0402
R115, R118, R207, R211, R234, R329, R330, R331, R407, R411, R434, R515, R516, R523: 33; OPL_R0402
R116, R122, R204, R404: 3k3; OPL_R0402
R124, R324: 100; OPL_R0402
R214, R328, R414: 13k3; OPL_R0402
R216, R218, R416, R418: 51k; OPL_R0402
R217, R417: 27k; OPL_R0402
R223, R423: 200k; OPL_R0402
R235, R435: 680; OPL_R0402
R310, R311, R312, R313, R314, R321: 88k7; OPL_R0402
R320: A1050; LDR
R325, R326: SPARE; OPL_R0402
R501, R509, R510, R511, R512, R513, R517, R521, R522: 15k; OPL_R0402
R502, R514: 1k5; OPL_R0402
R503, R504, R505, R506, R507, R508, R519, R520: 22; OPL_R0402
TP101, TP102, TP103, TP104, TP106, TP107, TP201, TP202, TP203, TP301, TP401, TP402, TP403: TESTPOINT; Wire_28AWG
TP501: CH1_RIGHT; Wire_28AWG
TP502: CH2_RIGHT; Wire_28AWG
TP503: CH3_RIGHT; Wire_28AWG
U101, U208, U408: MCP23008; OPL_TSSOP20-0.65-6.5X4.4MM
U102, U307, U308: IP4234CZ6; OPL_SOT-23-6
U103, U107: MCP4351; OPL_TSSOP20-0.65-6.5X4.4MM
U104: 74HCT138; SOIC16
U105, U110, U111, U112, U113: 74LV1T125; OPL_SOT-23-5
U106, U201, U205, U401, U405: MCP6004T; SOIC14
U108, U204, U404: 74LVC4066; SOIC14
U109, U202, U203, U206, U402, U403, U406: 74LVC1G3157; OPL_SOT-23-6
U207, U407: MCP6S26; SOIC14
U301: MCP23017; SOIC28
U304: MCP3008; SOIC16
U305: MCP1703A-2502/MB; OPL_SOT-89
U306: TPS54302; OPL_SOT-23-6
U501, U502, U505: CM108B; LQFP-48_7x7mm_Pitch0.5mm
U503: TUSB2036; LQFP-32_7x7mm_Pitch0.8mm
U504: MCP1703A-3302/MB; OPL_SOT-89
VR301: VRM2596; mod20x44
Y501: 6MHz; Crystal_HC49-SD_SMD

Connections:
+2V5: C310.1, C311.1, J307.1, J307.2, R102.1, R109.1, R117.2, R123.1, R201.1, R203.1, R206.1, R208.1, R209.1, R210.1, R214.1, R222.1, R225.1, R229.1, R233.1, R243.1, R302.1, R308.1, R401.1, R403.1, R406.1, R408.1, R409.1, R410.1, R414.1, R422.1, R425.1, R429.1, R433.1, R443.1, U103.3, U103.10, U103.13, U103.18, U107.3, U107.10, U107.13, U107.18, U201.10, U207.8, U305.3, U401.10, U407.8
+3.3VP: C521.2, C531.1, C532.1, R501.2, R513.1, R517.2, U503.3, U503.8, U503.22, U503.23, U503.25, U503.26, U504.3
+3V3: J101.1, J102.1, J107.1, J107.17, J307.5, J307.6, J311.2, J312.1, J315.2, Q101.1, Q103.1, Q104.1, R104.1, R110.1, R112.1, U102.5, U111.5, U112.5, U307.5
+5V: C101.2, C111.1, C112.2, C202.2, C215.1, C303.1, C308.1, C309.1, C326.2, C402.2, C415.1, J107.2, J107.4, J111.1, J307.3, J307.4, J311.1, JP301.1, Q501.2, R101.2, R105.1, R111.1, R113.1, R115.2, R118.2, R207.2, R211.2, R227.2, R234.2, R244.1, R301.2, R320.1, R324.2, R329.2, R330.2, R331.2, R407.2, R411.2, R427.2, R434.2, R444.1, R518.2, U101.4, U101.5, U101.20, U103.7, U104.6, U104.16, U105.5, U107.7, U109.5, U110.5, U113.5, U202.5, U203.5, U206.5, U208.5, U208.20, U301.9, U301.17, U304.16, U308.5, U402.5, U403.5, U406.5, U408.4, U408.20, VR301.3
+5VP: C501.1, C502.1, C503.1, C504.1, C529.1, C530.1, C539.1, C543.1, Q501.3, R515.2, R516.2, R523.2, U501.35, U502.35, U504.2, U504.4, U505.35
+12V: C319.1, C320.1, P301.5, R321.1, R325.1, U306.3, VR301.1
/CE0_33: J107.24, U104.5
/CH1/CTCSS_FROM_RADIO: R203.2, R204.1, U203.1
/CH1/CTCSS_FROM_RX_AUDIO: C209.2, C213.1, R224.1, U201.1, U202.1
/CH1/PORT_DET_EN: U203.6, U208.18
/CH1/PTT: C227.1, J204.4, Q201.3
/CH1/RX_AUDIO: C206.2, C230.1, J204.1
/CH1/RX_BUS1_EN: U204.12, U208.13
/CH1/RX_BUS2_EN: U204.13, U208.14
/CH1/RX_BUS3_EN: U204.5, U208.15
/CH1/RX_COR: C229.1, J204.2, R239.1
/CH1/RX_CTCSS: C201.2, C228.1, J204.3, R238.2
/CH1/RX_DEEMP_EN: U206.6, U208.16
/CH1/RX_DESC_EN: U202.6, U208.17
/CH1/RX_LOCAL_EN: U204.6, U208.12
/CH1/TONE_FROM_PI: C222.1, R235.1, U103.20, U203.3
/CH1/TX_AUDIO: C214.1, C226.1, J204.5
/CH1/TX_CTCSS: C231.1, J204.8, R240.1, TP201.1, U205.1
/CH1/VDDA_1: C204.1, C205.1, R207.1, U201.4
/CH1/VDDA_2: C220.1, C221.1, R234.1, U204.14, U205.4
/CH1/VDDA_3: C207.1, C208.1, R211.1, U207.14
/CH2/CTCSS_FROM_RADIO: R403.2, R404.1, U403.1
/CH2/CTCSS_FROM_RX_AUDIO: C409.2, C413.1, R424.1, U401.1, U402.1
/CH2/PORT_DET_EN: U403.6, U408.18
/CH2/PTT: C427.1, J404.4, Q401.3
/CH2/RX_AUDIO: C406.2, C430.1, J404.1
/CH2/RX_BUS1_EN: U404.12, U408.13
/CH2/RX_BUS2_EN: U404.13, U408.14
/CH2/RX_BUS3_EN: U404.5, U408.15
/CH2/RX_COR: C429.1, J404.2, R439.1
/CH2/RX_CTCSS: C401.2, C428.1, J404.3, R438.2
/CH2/RX_DEEMP_EN: U406.6, U408.16
/CH2/RX_DESC_EN: U402.6, U408.17
/CH2/RX_LOCAL_EN: U404.6, U408.12
/CH2/TONE_FROM_PI: C422.1, R435.1, U107.20, U403.3
/CH2/TX_AUDIO: C414.1, C426.1, J404.5
/CH2/TX_CTCSS: C431.1, J404.8, R440.1, TP401.1, U405.1
/CH2/VDDA_1: C404.1, C405.1, R407.1, U401.4
/CH2/VDDA_2: C420.1, C421.1, R434.1, U404.14, U405.4
/CH2/VDDA_3: C407.1, C408.1, R411.1, U407.14
/COR1: J107.11, Q202.3
/COR2: J107.16, Q402.3
/DHT_5: J112.2, Q104.3, R113.2
/DHT_33: J107.7, Q104.2, R112.2
/LINK1C: J101.3, J102.3, Q102.3, U102.3
/LINK1O: J107.33, Q102.1
/LINK2C: J101.6, J102.6, Q105.3, U102.4
/LINK2O: J107.37, Q105.1
/MISO_33: J107.21, R120.2, R122.1
/MOSI_33: J107.19, U113.2
/PIXEL_33: J107.40, U105.2
/PTT1D: J107.15, Q201.1
/PTT2D: J107.22, Q401.1
/PWM0: J107.12, R235.2
/PWM1: J107.35, R435.2
/SC3_LINK1: U101.13, U108.13
/SC3_LINK2: U101.14, U108.5
/SC3_LINK_SEL: U101.15, U109.6
/SCL0_33: J107.28, J312.3, J315.3, U307.1
/SCL1_33: J107.5, Q101.2, R104.2
/SCLK_33: J107.23, U110.2
/SC_ENA: Q501.1, R518.1, U101.12
/SDA0_33: J107.27, J312.2, J315.4, U307.6
/SDA1_33: J107.3, Q103.2, R110.2
/SELA_33: J107.29, U104.1
/SELB_33: J107.31, U104.2
/SELC_33: J107.32, U104.3
/Spares, GPIO, and ADC/ADC0: P301.6, U304.1
/Spares, GPIO, and ADC/ADC1: P301.7, R310.1
/Spares, GPIO, and ADC/ADC2: J305.13, R311.1
/Spares, GPIO, and ADC/ADC3: J305.15, R312.1
/Spares, GPIO, and ADC/ADC4: J308.13, R313.1
/Spares, GPIO, and ADC/ADC5: J308.15, R314.1
/Spares, GPIO, and ADC/ADC_LIGHT: C306.1, R320.2, R322.1, U304.7
/Spares, GPIO, and ADC/ADC_VIN: C307.1, R321.2, R323.1, U304.8
/Spares, GPIO, and ADC/GPA0: J305.2, U301.21
/Spares, GPIO, and ADC/GPA1: J305.3, U301.22
/Spares, GPIO, and ADC/GPA2: J305.4, U301.23
/Spares, GPIO, and ADC/GPA3: J305.5, U301.24
/Spares, GPIO, and ADC/GPA4: J305.6, U301.25
/Spares, GPIO, and ADC/GPA5: J305.7, U301.26
/Spares, GPIO, and ADC/GPA6: J305.8, U301.27
/Spares, GPIO, and ADC/GPA7: J305.9, P301.9, U301.28
/Spares, GPIO, and ADC/GPB0: J308.2, U301.1
/Spares, GPIO, and ADC/GPB1: J308.3, U301.2
/Spares, GPIO, and ADC/GPB2: J308.4, U301.3
/Spares, GPIO, and ADC/GPB3: J308.5, U301.4
/Spares, GPIO, and ADC/GPB4: J308.6, U301.5
/Spares, GPIO, and ADC/GPB5: J308.7, U301.6
/Spares, GPIO, and ADC/GPB6: J308.8, U301.7
/Spares, GPIO, and ADC/GPB7: J308.9, P301.8, U301.8
/Spares, GPIO, and ADC/SCL0_OUT: J305.11, J308.11, U307.3
/Spares, GPIO, and ADC/SDA0_OUT: J305.10, J308.10, U307.4
/UINTA_5: U111.2, U301.20
/UINTA_33: J107.8, U111.4
/UINTB_5: U112.2, U301.19
/UINTB_33: J107.10, U112.4
/VDDA_3: C103.1, C104.1, R115.1, U106.4, U108.14
/soundcard/D_N: J501.2, R506.2
/soundcard/D_P: J501.3, R504.2
/soundcard/FROM_SND1: C527.1, R230.2
/soundcard/FROM_SND2: C528.1, R430.2
/soundcard/FROM_SND3: C540.1, R103.2
/soundcard/TO_SND1: C511.1, U203.4
/soundcard/TO_SND2: C512.1, U403.4
/soundcard/TO_SND3: C542.1, R116.1, R117.1
/soundcard/U1N: R508.1, R512.2, U501.42
/soundcard/U1P: R507.1, R511.2, U501.41
/soundcard/U2N: R505.1, R510.2, U502.42
/soundcard/U2P: R503.1, R509.2, U502.41
/soundcard/U3N: R520.1, R522.2, U505.42
/soundcard/U3P: R519.1, R521.2, U505.41
/~ADC_CS: U104.7, U304.10
/~CTCSS1: J107.13, Q203.3
/~CTCSS2: J107.18, Q403.3
/~PGA1_CS: U104.10, U207.10
/~PGA2_CS: U104.9, U407.10
/~R03CS: U103.4, U104.15
/~R47CS: U104.14, U107.4
/~UINT_ENA: U101.19, U111.1, U112.1
GND: C101.1, C103.2, C104.2, C106.2, C107.2, C111.2, C112.1, C202.1, C204.2, C205.2, C207.2, C208.2, C215.2, C220.2, C221.2, C222.2, C225.2, C226.2, C227.2, C228.2, C229.2, C230.2, C231.2, C303.2, C304.2, C305.2, C306.2, C307.2, C308.2, C309.2, C310.2, C311.2, C312.2, C313.2, C314.2, C315.2, C316.2, C317.2, C318.2, C319.2, C320.2, C322.2, C323.2, C324.2, C325.2, C326.1, C402.1, C404.2, C405.2, C407.2, C408.2, C415.2, C420.2, C421.2, C422.2, C425.2, C426.2, C427.2, C428.2, C429.2, C430.2, C431.2, C501.2, C502.2, C503.2, C504.2, C505.2, C506.2, C507.2, C508.2, C513.2, C514.2, C515.2, C516.2, C517.2, C518.2, C519.2, C520.2, C521.1, C522.2, C523.2, C524.2, C525.2, C526.2, C529.2, C530.2, C531.2, C532.2, C533.2, C534.2, C535.2, C536.2, C537.2, C538.2, C539.2, C543.2, GND101.1, GND102.1, GND103.1, GND104.1, J101.4, J102.4, J107.6, J107.9, J107.14, J107.20, J107.25, J107.30, J107.34, J107.39, J111.3, J112.4, J204.6, J204.7, J204.9, J305.12, J305.14, J308.12, J308.14, J311.6, J312.5, J315.1, J404.6, J404.7, J404.9, J501.5, P301.2, P301.3, P301.4, PROTO301.1, Q102.2, Q105.2, Q201.2, Q202.2, Q203.2, Q401.2, Q402.2, Q403.2, R122.2, R241.2, R242.2, R302.2, R309.2, R315.2, R316.2, R317.2, R318.2, R319.2, R322.2, R323.2, R326.2, R328.2, R441.2, R442.2, R509.1, R510.1, R511.1, R512.1, R521.1, R522.1, U101.3, U101.9, U102.2, U103.17, U104.4, U104.8, U105.1, U105.3, U106.10, U106.11, U106.12, U107.17, U108.6, U108.7, U108.8, U108.11, U108.12, U109.2, U110.1, U110.3, U111.3, U112.3, U113.1, U113.3, U201.11, U202.2, U203.2, U204.7, U205.11, U206.2, U207.9, U208.3, U208.4, U208.9, U301.10, U301.15, U301.16, U304.9, U304.14, U305.1, U306.1, U307.2, U308.2, U401.11, U402.2, U403.2, U404.7, U405.11, U406.2, U407.9, U408.3, U408.5, U408.9, U501.10, U501.14, U501.16, U501.22, U501.23, U501.24, U501.33, U501.36, U502.10, U502.14, U502.16, U502.22, U502.23, U502.24, U502.33, U502.36, U503.7, U503.21, U503.24, U503.28, U503.31, U504.1, U505.10, U505.14, U505.16, U505.22, U505.23, U505.24, U505.33, U505.36, VR301.2, VR301.4
LINK1_AUD: J101.2, J102.2, R107.1, R219.1, R419.1, U109.1, U207.4, U407.4
LINK2_AUD: J101.5, J102.5, R114.1, R226.1, R426.1, U109.3, U207.5, U407.5
LOCAL_LINK_AUD: R123.2, R215.1, R415.1, U207.3, U407.3
MISO_5: R120.1, U103.16, U107.16, U304.12
MOSI_5: U103.6, U107.6, U113.4, U207.11, U304.11, U407.11
unnamed: C102.1, R106.2, R108.1, U106.7
unnamed: C102.2, R108.2, R109.2, U106.6
unnamed: C106.1, C107.1, J112.1, R118.1
unnamed: C201.1, R201.2, R202.2
unnamed: C203.1, R205.1, TP202.1, U202.3, U205.14
unnamed: C203.2, R205.2, R206.2, U205.13
unnamed: C206.1, R210.2, R213.2
unnamed: C209.1, C210.2, R217.1
unnamed: C210.1, R214.2, U201.5
unnamed: C211.1, R221.1, TP203.1, U201.14, U204.1, U204.4, U204.8, U204.11
unnamed: C211.2, R221.2, R222.2, U201.13
unnamed: C212.1, R223.1, U206.3
unnamed: C212.2, R216.1, R218.2, R223.2, U201.9
unnamed: C213.2, R224.2, R225.2, U201.2
unnamed: C214.2, C217.1, R228.1, U205.8
unnamed: C217.2, R228.2, R229.2, U205.9
unnamed: C219.1, R231.2, R232.1, U205.7
unnamed: C219.2, R232.2, R233.2, U205.6
unnamed: C223.1, R236.1, R237.2
unnamed: C223.2, R240.2, R243.2, U205.2
unnamed: C225.1, R237.1, U205.3
unnamed: C304.1, C305.1, R308.2, R309.1, U304.15
unnamed: C312.1, C313.1, R324.1, U305.2, U305.4
unnamed: C314.1, R310.2, R315.1, U304.2
unnamed: C315.1, R311.2, R316.1, U304.3
unnamed: C316.1, R312.2, R317.1, U304.4
unnamed: C317.1, R313.2, R318.1, U304.5
unnamed: C318.1, R314.2, R319.1, U304.6
unnamed: C321.1, U306.6
unnamed: C321.2, L301.2, U306.2
unnamed: C322.1, C323.1, C324.1, C325.1, JP301.2, L301.1, R327.1
unnamed: C401.1, R401.2, R402.2
unnamed: C403.1, R405.1, TP402.1, U402.3, U405.14
unnamed: C403.2, R405.2, R406.2, U405.13
unnamed: C406.1, R410.2, R413.2
unnamed: C409.1, C410.2, R417.1
unnamed: C410.1, R414.2, U401.5
unnamed: C411.1, R421.1, TP403.1, U401.14, U404.1, U404.4, U404.8, U404.11
unnamed: C411.2, R421.2, R422.2, U401.13
unnamed: C412.1, R423.1, U406.3
unnamed: C412.2, R416.1, R418.2, R423.2, U401.9
unnamed: C413.2, R424.2, R425.2, U401.2
unnamed: C414.2, C417.1, R428.1, U405.8
unnamed: C417.2, R428.2, R429.2, U405.9
unnamed: C419.1, R431.2, R432.1, U405.7
unnamed: C419.2, R432.2, R433.2, U405.6
unnamed: C423.1, R436.1, R437.2
unnamed: C423.2, R440.2, R443.2, U405.2
unnamed: C425.1, R437.1, U405.3
unnamed: C505.1, C506.1, R515.1, U501.29, U501.34
unnamed: C507.1, C508.1, R516.1, U502.29, U502.34
unnamed: C509.1, TP501.1
unnamed: C509.2, U501.32
unnamed: C510.1, TP502.1
unnamed: C510.2, U502.32
unnamed: C511.2, U501.27
unnamed: C512.2, U502.27
unnamed: C513.1, U501.26
unnamed: C514.1, U502.26
unnamed: C515.1, U501.37
unnamed: C516.1, U501.8
unnamed: C517.1, U501.7, U501.9, U501.38
unnamed: C518.1, U502.37
unnamed: C519.1, U502.8
unnamed: C520.1, U502.7, U502.9, U502.38
unnamed: C522.1, R501.1, U503.4
unnamed: C523.1, R502.2, R504.1, U503.1
unnamed: C524.1, R506.1, U503.2
unnamed: C525.1, U503.30, Y501.1
unnamed: C526.1, R514.2, Y501.2
unnamed: C527.2, U501.30
unnamed: C528.2, U502.30
unnamed: C533.1, U505.37
unnamed: C534.1, C536.1, R523.1, U505.29, U505.34
unnamed: C535.1, U505.8
unnamed: C537.1, U505.7, U505.9, U505.38
unnamed: C538.1, U505.26
unnamed: C540.2, U505.30
unnamed: C541.1, TP503.1
unnamed: C541.2, U505.32
unnamed: C542.2, U505.27
unnamed: J107.26, TP103.1
unnamed: J107.36, U102.1
unnamed: J107.38, U102.6
unnamed: J111.2, R124.1
unnamed: J305.1, R329.1
unnamed: J308.1, R330.1
unnamed: J311.3, TP301.1
unnamed: J311.4, U308.4
unnamed: J311.5, U308.3
unnamed: P301.1, R331.1
unnamed: Q202.1, R239.2, R241.1
unnamed: Q203.1, R238.1, R242.1
unnamed: Q402.1, R439.2, R441.1
unnamed: Q403.1, R438.1, R442.1
unnamed: R101.1, U101.6
unnamed: R102.2, R103.1, U106.5
unnamed: R106.1, U108.1, U108.4
unnamed: R107.2, U108.2
unnamed: R114.2, U108.3
unnamed: R116.2, U106.1, U106.2
unnamed: R124.2, U105.4
unnamed: R202.1, U103.8
unnamed: R204.2, U202.4
unnamed: R208.2, R212.1, U207.2
unnamed: R209.2, R230.1, U205.5
unnamed: R212.2, U204.9
unnamed: R213.1, U103.11
unnamed: R215.2, U204.10
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

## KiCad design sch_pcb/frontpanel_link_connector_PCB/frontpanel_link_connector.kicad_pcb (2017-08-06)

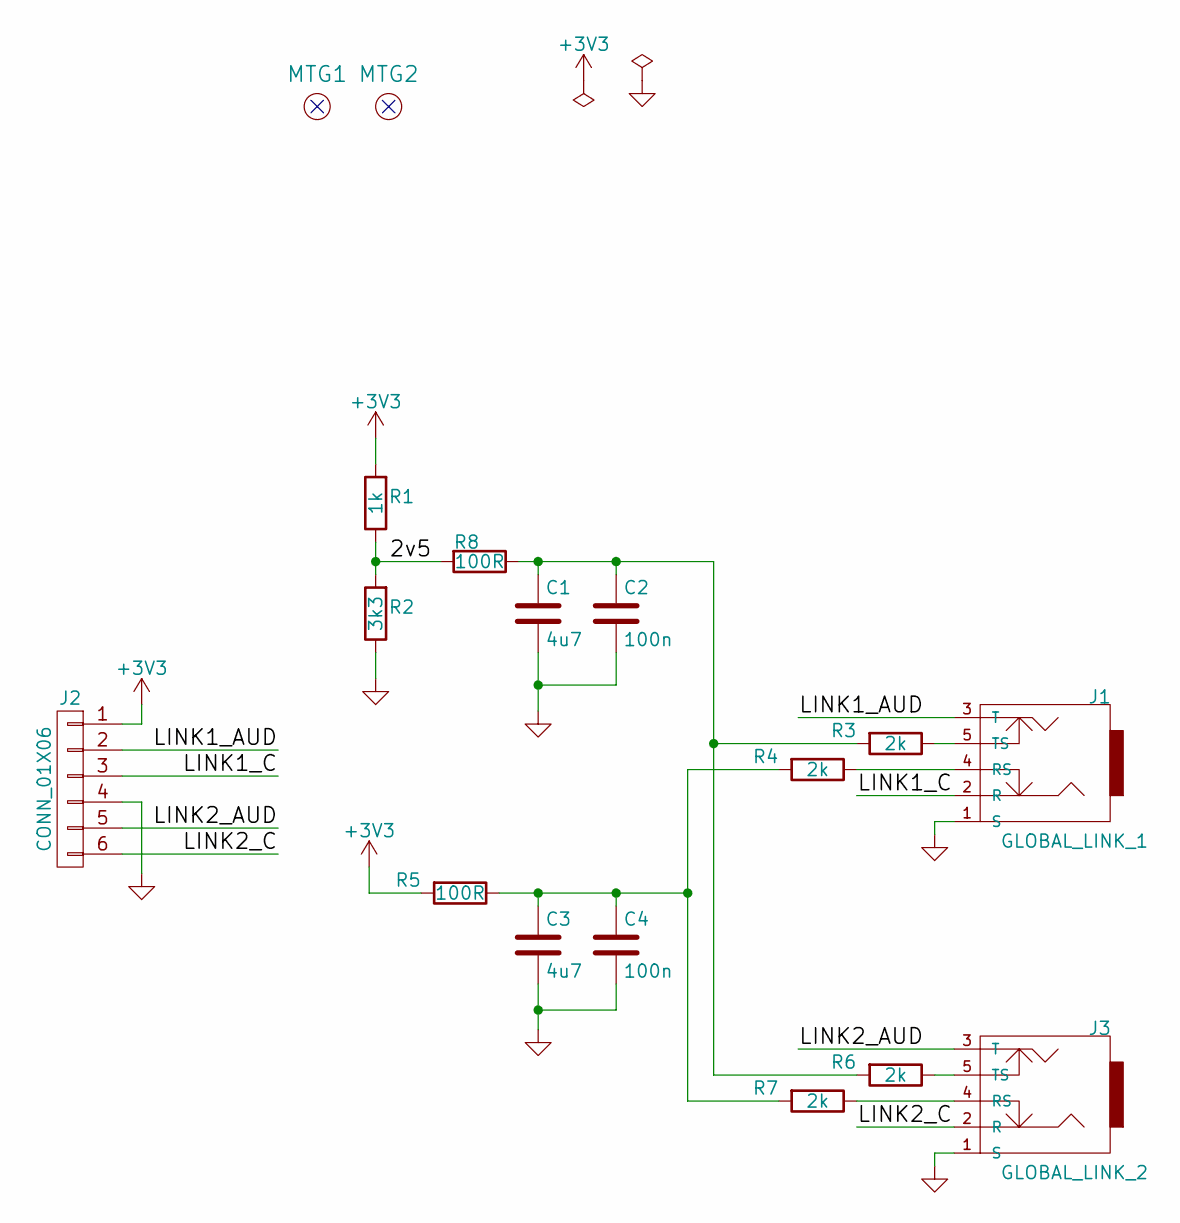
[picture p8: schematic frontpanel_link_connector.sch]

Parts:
C1, C3: 4u7; smd0603
C2, C4: 100n; smd0603
J1: GLOBAL_LINK_1; TRS3.5_5
J2: CONN_01X06; Molex_22-27-2061_100mil_6pin_verical
J3: GLOBAL_LINK_2; TRS3.5_5
MTG1, MTG2: MOUNTING_HOLE; MTG_4_40
R1: 1k; smd0603
R2: 3k3; smd0603
R3, R4, R6, R7: 2k; smd0603
R5, R8: 100R; smd0603

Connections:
+3V3: J2.1, R1.2, R5.2
/2v5: R1.1, R2.2, R8.2
/LINK1_AUD: J1.3 (T), J2.2
/LINK1_C: J1.2 (R), J2.3
/LINK2_AUD: J2.5, J3.3 (T)
/LINK2_C: J2.6, J3.2 (R)
GND: C1.2, C2.2, C3.2, C4.2, J1.1 (S), J2.4, J3.1 (S), R2.1
unnamed: C1.1, C2.1, R3.2, R6.2, R8.1
unnamed: C3.1, C4.1, R4.2, R5.1, R7.2
unnamed: J1.4 (RS), R4.1
unnamed: J1.5 (TS), R3.1
unnamed: J3.4 (RS), R7.1
unnamed: J3.5 (TS), R6.1

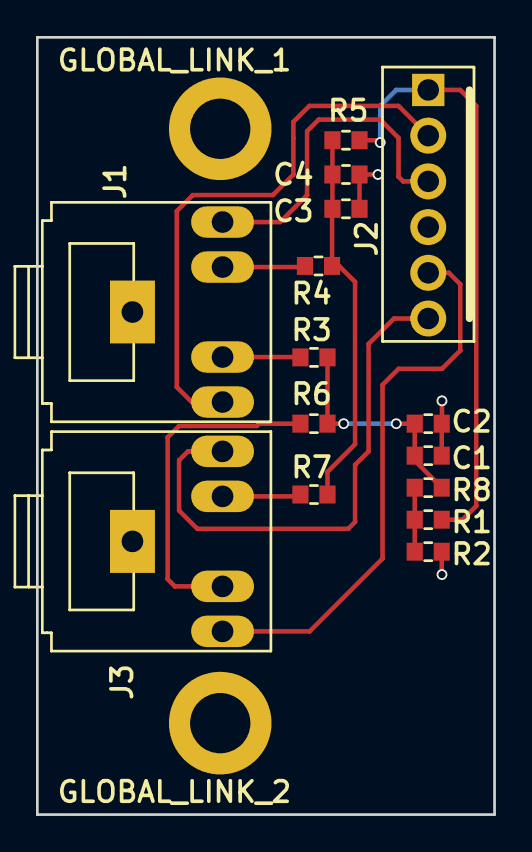
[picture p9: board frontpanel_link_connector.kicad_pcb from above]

Board: 2 copper layers, 25.4 x 43.2 mm, 17 parts (0 on the bottom side), 13 nets.

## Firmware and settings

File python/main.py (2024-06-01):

#!/usr/bin/python3
# This is the main repeater code
#
# basic flow
# 1) create the instances for the 2 ports.
# 2) run auto tune routine to find which soundcard is connected to which port (TBD)
# 3) Load xml config
# 4) Annotate the ports with their sound card
# 5) start thread for gui (daemon) (tbd)
# 6) start thread for command back ends (daemon) (tdb) 
# 7) start the threads for the 2 ports by calling their run methods as deamons
# wait forever
import sys
import time
import socket
import os.path
try:
    import RPi.GPIO as GPIO
except:
    sys.path.append('hostsim')
    import RPi.GPIO as GPIO
import subprocess
import threading
import radioPort
import datetime
import signal, os
import code
import re
import queue
from multiprocessing import Process
import state
import fpPixels
import tcpSocketCmd
import socketPython
import ipPort

def create_parser():
    """ Create an object to parse the command line arguments."""
    from optparse import OptionParser
    usage = "Usage: %s [options]" %__file__
    parser = OptionParser(usage)
    parser.add_option("--writeXML", "-w", dest="writeXML", default=False,
                      action="store_true",
                      help="""read in current XML config (if one can be found)
or use built in defaults. Then write out a config file for editing."""
                      )
    parser.add_option("--verbose", "-v", dest="verbose", default=False,
                      action="store_true",
                      help="""Print extra debug messages"""
                      )
    parser.add_option("--portdetect", "-d", dest="portdetect", default=False,
                      action="store_true",
                      help="""force port detection even if configured off"""
                      )
    parser.add_option("--exitafterdetection", "-e", dest="exitdetect", default=False,
                      action="store_true",
                      help="""force port detection even if configured off then exit"""
                      )
    parser.add_option("--nosound", "-n", dest="nosound", default=False,
                      action="store_true",
                      help="""configure all ports to onboard sound output only"""
                      )
    parser.add_option("--tunekenwood", "-k", dest="tunekenwood", default=False,
                      action="store_true",
                      help="""Go into tune kenwood mode"""
                      )
    return parser
class top:
    def __init__ (self) :
        self.host = socket.gethostname()
        self.installPath = os.path.dirname(os.path.realpath(__file__))
        self.localPath = os.path.abspath(self.installPath + "/../" + self.host)
        self.xmlvars = []
        self.options = {}
    def findFileOnPath (self,baseNameList) :
        for basename in baseNameList :
            for f in [os.path.join(self.localPath,basename), os.path.join(self.installPath,basename)] :
                if os.path.isfile(f) :
                    return f
        return False
    def absPath(self,file) :
        return (os.path.abspath(os.path.join(self.installPath,file)))
top = top()
parser= create_parser()
top.options,args = parser.parse_args()
sys.path.insert(0,top.localPath)
import gui
from logit import logit
import xmlio
import hwio as HWIO
cmdFile = top.findFileOnPath([top.host + 'Cmd.py', 'mycmd.py'])
if cmdFile :
    logit("Load command file: " + cmdFile)
    exec(compile(open(cmdFile).read(), cmdFile, 'exec'))
    logit("Command file Load done")

def hup_handler(signum, frame):
    print('Hup interrupt, Going interactive', signum)
    code.interact(local=dict(globals(), **locals()))

def int_handler(signum, frame):
    print('Int interrupt, Shutting down', signum)
    port1.tx.down()
    port2.tx.down()
    print("turning off sound cards and GPIO interupts")
    hwio.i2cBus.write_byte_data(HWIO.GPIOEX3, HWIO.GPIOR,129)
    GPIO.cleanup()
    fp.cleanup()
    #p0.terminate()
    sys.exit(-1)
signal.signal(signal.SIGHUP, hup_handler)
signal.signal(signal.SIGINT, int_handler)

# lists of the data that will be stored in the xml configuration
xmlvars = ( )
GPIO.setmode(GPIO.BOARD)
q1 = queue.Queue()
q2 = queue.Queue()

if(top.options.tunekenwood) :
    import kenwoodTK
    top.kenwood=kenwoodTK.kenwoodTK()
    
gui = gui.gui(top)
top.gui=gui
globalState = state.state(top,gui)
top.globalState=globalState
port1 = radioPort.radioPort(1, q1, globalState)
port2 = radioPort.radioPort(2, q2, globalState)
port1.other = port2
port2.other = port1
top.port1 = port1
top.port2 = port2
port3 = ipPort.ipPort(top)
top.port3=port3
hwio = HWIO.hwio(top)
port1.hwio = hwio
port2.hwio = hwio
top.hwio=hwio
fp = fpPixels.fpPixels(top.globalState)
cmdSock = tcpSocketCmd.tcpSocketCmd(globals(), q1,q2)
sp = socketPython.socketPython((dict(globals(), **locals())))
# load the config
logit("Load XML config")
xmlFile = top.findFileOnPath([top.host + '.xml', 'config.xml'])
if xmlFile :
    logit("Load XML config : " + xmlFile )
    xmlio.loadXml(top,xmlFile)
logit("Load XML Done")
if(top.options.writeXML) :
    gui.guiSave()
    exit(0)
if(gui.gui) :
    gui.init()
hwio.init_all()
# commend out the fp.connect when no pixes to reduce load and hangs
fp.connect()
if(top.options.tunekenwood) :
    #port1.isLink = True
    #port1.linkState = 3
    #port1.rxThread = threading.Thread(target=port1.rx.run)
    #port1.rxThread.daemon = True
    #port1.rxThread.start()
    
    #if (gui.gui) :
    #    gui.run()
    pass

if(port1.enabled) :
    port1.fsmThread = threading.Thread(target=port1.run)
    port1.fsmThread.daemon = True
    port1.fsmThread.start()
    port1.cmdThread = threading.Thread(target=cmdprocess, args=(q1,port1))
    port1.cmdThread.daemon = True
    port1.cmdThread.start()
if(port2.enabled) :
    port2.fsmThread = threading.Thread(target=port2.run)
    port2.fsmThread.daemon = True
    port2.fsmThread.start()
    port2.cmdThread = threading.Thread(target=cmdprocess, args=(q2,port2))
    port2.cmdThread.daemon = True
    port2.cmdThread.start()

#g = threading.Thread(target=gui.run)
#g.daemon = True
#g.start()
hwioIThread = threading.Thread(target=hwio.runUInts)
hwioIThread.daemon = True
hwioIThread.start()
hwioAThread = threading.Thread(target=hwio.runAdc)
hwioAThread.daemon = True
hwioAThread.start()
cmdSockThread = threading.Thread(target=cmdSock.run)
cmdSockThread.daemon = True
cmdSockThread.start()
spThread = threading.Thread(target=sp.run)
spThread.daemon = True
spThread.start()
if (gui.gui) :
    gui.run()
else:
    while(True) :
        time.sleep(100)

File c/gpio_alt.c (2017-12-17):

    /*
    Utility to switch Raspberry-Pi GPIO pin functions
    Tim Giles 01/04/2013

    Usage:
    $ gpio_alt -p PIN_NUMBER -f ALT_NUMBER

    Based on RPi code from Dom and Gert, 15-Feb-2013, <http://elinux.org/RPi_Low-level_peripherals#C_2>
    and Gnu getopt() example <http://www.gnu.org/software/libc/manual/html_node/Example-of-Getopt.html#Example-of-Getopt>
    */

    #include <ctype.h>
    #include <stdio.h>
    #include <stdlib.h>
    #include <unistd.h>
    #include <fcntl.h>
    #include <sys/mman.h>

//    #define BCM2708_PERI_BASE        0x20000000 // pi zero
#define BCM2708_PERI_BASE        0x3f000000 // Pi 2 and 3
    #define GPIO_BASE                (BCM2708_PERI_BASE + 0x200000) /* GPIO controller */
    #define PAGE_SIZE (4*1024)
    #define BLOCK_SIZE (4*1024)

    int  mem_fd;
    void *gpio_map;
    volatile unsigned *gpio;
    void setup_io();

    // GPIO setup macros. Always use INP_GPIO(x) before using OUT_GPIO(x) or SET_GPIO_ALT(x,y)
    #define INP_GPIO(g) *(gpio+((g)/10)) &= ~(7<<(((g)%10)*3))
    #define OUT_GPIO(g) *(gpio+((g)/10)) |=  (1<<(((g)%10)*3))
    #define SET_GPIO_ALT(g,a) *(gpio+(((g)/10))) |= (((a)<=3?(a)+4:(a)==4?3:2)<<(((g)%10)*3))

    #define GPIO_SET *(gpio+7)  // sets   bits which are 1 ignores bits which are 0
    #define GPIO_CLR *(gpio+10) // clears bits which are 1 ignores bits which are 0



    int main (int argc, char **argv) {
      int opt, flag, n_pin, n_alt;
      flag=0;

      while ((opt = getopt (argc, argv, "hp:f:")) != -1) {
        switch (opt) {
        case 'h':
          break;
        case 'p':
          n_pin = atoi(optarg); flag |= 0b0001; break;
        case 'f':
          n_alt = atoi(optarg); flag |= 0b0010; break;
        case '?':
          // getopt() prints error messages, so don't need to repeat them here
          return 1;
        default:
          abort ();
        }
      }
     
      if (flag != 0b0011) {
        fprintf (stderr, "Usage:\n$ gpio_alt -p PIN_NUM -f FUNC_NUM\n");
        return 1;
      }
     
      setup_io(); // Set up gpi pointer for direct register access
      INP_GPIO(n_pin);  // Always use INP_GPIO(x) before using SET_GPIO_ALT(x,y)
      SET_GPIO_ALT(n_pin, n_alt);
     
      printf("Set pin %i to alternative-function %i\n", n_pin, n_alt);
     
      return 0;
    }



    void setup_io() {
       /* open /dev/mem */
       if ((mem_fd = open("/dev/mem", O_RDWR|O_SYNC) ) < 0) {
          printf("can't open /dev/mem \n");
          exit(-1);
       }

       /* mmap GPIO */
       gpio_map = mmap(
          NULL,             //Any adddress in our space will do
          BLOCK_SIZE,       //Map length
          PROT_READ|PROT_WRITE,// Enable reading & writting to mapped memory
          MAP_SHARED,       //Shared with other processes
          mem_fd,           //File to map
          GPIO_BASE         //Offset to GPIO peripheral
       );

       close(mem_fd); //No need to keep mem_fd open after mmap

       if (gpio_map == MAP_FAILED) {
          printf("mmap error %d\n", (int)gpio_map);//errno also set!
          exit(-1);
       }

       // Always use volatile pointer!
       gpio = (volatile unsigned *)gpio_map;
    }

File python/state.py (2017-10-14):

def defaultCallback(object, value) :
    print( 'object ' + object + ' was set to ' + str(value))
 
def voltageAlarm(name,value) :
    if(value < 10.5) :
        print( "voltage %s too low: %d" %(name,value))
    elif (value >13.6) :
        print( "voltage %s too high: %d" %(name,value))
    else :
        print( "voltage %s OK: %d" %(name,value))
 
class GlobalData(object):
    def __init__(self, name, defValue=False, callbacks=None):
        self._value = defValue
        self.callbacks = callbacks if callbacks else list()
        self.name = name
    @property
    def value(self):
        return(self._value)
    @value.setter
    def value(self,value) :
        self.setValue(self,value)
    def setValue(self,value,color=None) :
        if(self._value != value or True) :
            self._value = value
            self._color = color
            for callback in self.callbacks:
                if(color == None) :
                    callback(self.name,self.value)
                else :
                    callback(self.name,self.value,color)
    def addCallback(self,callback):
        if callable(callback):
            self.callbacks.append(callback)
        else:
            print("Callback is not callable")
    def rmCallback(self,callback) :
        self.callbacks.remove(callback)

class state(object):    
    def __init__(self,top,gui) :
        self.top = top
        self.cor1 = GlobalData('cor1')
        self.ctcss1 = GlobalData('ctcss1')
        self.cmd1 = GlobalData('cmd1')
        self.softCtcss1 = GlobalData('softCtcss1')
        self.tx1 = GlobalData('tx1')
        self.cor2 = GlobalData('cor2')
        self.ctcss2 = GlobalData('ctcss2')
        self.cmd2 = GlobalData('cmd2')
        self.softCtcss2 = GlobalData('softCtcss2')
        self.tx2 = GlobalData('tx2')
        self.battVolts = GlobalData('Battvolts')
        if(gui.gui) :
            self.cor1.addCallback(gui.updateItem)
            self.ctcss1.addCallback(gui.updateItem)
            self.cmd1.addCallback(gui.updateItem)
            self.softCtcss1.addCallback(gui.updateArray)
            self.tx1.addCallback(gui.updateItem)
            self.cor2.addCallback(gui.updateItem)
            self.ctcss2.addCallback(gui.updateItem)
            self.cmd2.addCallback(gui.updateItem)
            self.softCtcss2.addCallback(gui.updateArray)
            self.tx2.addCallback(gui.updateItem)

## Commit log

2017-03-25 now with tout generator and minor bug fixes.
    [audioCtl.py, rpt.py, tail.py]
2017-04-07 timers should not start by default, wait until needed
2017-04-10 basic working timer ID timers and commands Yeah we have an alpha level
2017-04-11 turn down some debug messages, correct a typo in polite Id
    [rptFsm.py]
2017-04-24 Some documentation and state machine cleanup. Adding i2c control for extra gpio
2017-04-26 more i2c setup
2017-04-29 change print to work on both 2.7 and 3.0
2017-04-29 adding a picture of flow as png
2017-06-11 debug initial linking and syntax errors
    [gui.py, hwio.py, mycmd.py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]
2017-06-12 added some notes about pcb vendor sites
2017-06-20 add delay between calls to update to collect calls on their own thread
2017-06-21 cleanup, disconnected leds
2017-06-28 set up command socket port
2017-06-30 added socket python back door
2017-07-01 protect i2c/smbus calls to allow runnining without hardware
2017-07-04 debug socket connnections and re-connecting
2017-07-04 Add files via upload
    Initial upload of schematic and (barely started) PCB layout
    [PiPtr.kicad_pcb, PiPtr.sch, audioChannel.sch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]
2017-07-06 Updates based on emails
    Disconnect SDO on PGAs
    Add mounting holes
    More placement on PCB - for now, delete all 4xx sheet footprints. Once channel 1 is placed, it will get copied to make channel 2.
    [PiPtr.kicad_pcb, PiPtr.sch, audioChannel.sch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]
2017-07-07 start to stage for last slider.
2017-07-07 Add files via upload
    Fix missing pin numbers on opamps
    Change two 4.7uF caps in parallel to 10uF/0805. This will save 6 caps and will handle capacitance loss due to DC bias better
    Change 2 22uF caps to 4 10uF caps to get rid of an extra BOM line item
    More work on placement. The channel now fits in the space allocated to it.
    Connectors need to be revisited - GPIO and soundcard
    [PiPtr.kicad_pcb, audioChannel.sch, spares.sch]
2017-07-08 add checkboxes and control for analog switches
2017-07-09 Add files via upload
    Changed user_adc connector to 2x7 (14-pin is a lot more common than 12-pin)
    Changed user_gpio connector to 2 2x8 connectors. 1x20 takes too much linear space
    First pass layout on the two audio channels. Right now, board is 4-layer, 100x150mm. May be able to knock down the 150mm dimension
    The link and soundcard connectors fit in a row across the front edge.
    [PiPtr.kicad_pcb, PiPtr.sch, audioChannel.sch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]
2017-07-10 Add files via upload
    Reversed ends on all pots so up increases level
    Added outline and mounting holes to RasPi footprint so we can see how big it really is
    Moved parts away from one of the RasPi mounting holes so we can use all 4 of them
    More routing - finished user GPIO and ADC, SPI chipselect decoder
    Still to do: level shifters, RasPi connections and spares
    [PiPtr.kicad_pcb, PiPtr.sch, audioChannel.sch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]
2017-07-18 Add files via upload
    Change link connectors to use a daughterboard for the off-rack links and 100mil headers for between-board links
    [PiPtr.kicad_pcb, PiPtr.sch, audioChannel.sch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]
2017-07-27 Add soundcard schematic
    [PiPtr.kicad_pcb, PiPtr.sch, audioChannel.sch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]
2017-07-27 Add PCB models
2017-07-29 Update to soundcard
    Split AVdd and DVdd
    Add caps and testpoints for right outputs
    Move active outputs to left channel
    [PiPtr.sch, audioChannel.sch, soundcard.sch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]
2017-07-30 Update from latest round of emails
    Change connectors - use correct footprint for DE9F. Add chassis connector as DE9M, AUX_IO connectors as 116-pin ribbon, expected to transition to DA15 with a cable.
    Remove screw terminals for 12V input as it now comes in on chassis connector
    Remove third EEPOT package
    Move stuff off PCB in preparation to incorporate all the schematic updates.
    [PiPtr.kicad_pcb, PiPtr.sch, audioChannel.sch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]
2017-08-06 Add files via upload
    Just realized these never got committed...
    [frontpanel_link_connector.kicad_pcb, frontpanel_link_connector.sch]
2017-08-06 Delete DE15HD_M_Right_Angle_HD15_plug.kicad_mod
    Committed to wrong place; moved to lib.pretty
2017-08-06 Delete DE9F_Right_Angle.kicad_mod
    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
2017-08-06 Delete DE9M_Right_Angle.kicad_mod
    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
2017-08-06 Delete Diode_SMB.kicad_mod
    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
2017-08-06 Add files via upload
    More routing of the PCB.... Slowly getting there.
    [PiPtr.kicad_pcb, PiPtr.sch, audioChannel.sch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]
2017-08-08 Add files via upload
    Remove OLED connector
    Remove extra bypass cap from third EEPOT
    More routing - got the soundcards and usb hub done. Only remaining big section is the DC-DC. Still a bit of pain-in-the-tuchas traces that need to sneak across the board...
    [PiPtr.kicad_pcb, PiPtr.sch, audioChannel.sch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]
2017-08-10 Add files via upload
    Fix sheet ordering in schematic
    Finish routing (except USB connector...)
    Still to do: USB connector, cleanup PCB, fix refdes positions
    [PiPtr.kicad_pcb, PiPtr.sch, audioChannel.sch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]
2017-08-11 Add files via upload
    Add USB connector. Pull back corner of board for it so the main board connector is around the same depth as the one on the Pi
    Finish moving all refdes to avoid pads, other silk, and vias
    Some routing cleanup
    [PiPtr.kicad_pcb, PiPtr.sch, audioChannel.sch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]
2017-08-12 fix up file path searching in main and radioport
    [main.py, radioPort.py]
2017-08-13 Flip pi
    Whoops. For all this time, the pi footprint was backwards, as if this board was a hat mounting on top of the pi. Flip it so the pi mounts face down on this board. This will put the network and usb connections towards the rear panel, so move it forward as far as possible to make room.
    [PiPtr.kicad_pcb]
2017-08-13 Silk cleanup
    [PiPtr.kicad_pcb]
2017-08-21 Add files via upload
    Add a PMOS switch to allow turning on the soundcard section (hub and 2 soundcard chips) after the Pi has booted. For some reason, doing so before the desktop loads causes it to hang..
    Change gain resistors in opamp stages to move the sweet spot closer to the center of the digital pots to allow for more adjustment range
    [PiPtr.kicad_pcb, PiPtr.sch, audioChannel.sch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]
2017-08-29 Add prototype area and soic-a8 footprints
2017-08-29 Update board with third soundcard
    [PiPtr.kicad_pcb, PiPtr.sch, audioChannel.sch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]
2017-09-04 Add minimum load on 2v5 regulator. Update gain to soundcard 1 and 2
    [PiPtr.kicad_pcb, audioChannel.sch, spares.sch]
2017-09-07 BOM scrub
    [PiPtr.kicad_pcb, PiPtr.sch, audioChannel.sch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]
2017-09-13 Move link connector close to edge to allow using jumpers to connect boards
    [PiPtr.kicad_pcb, PiPtr.sch, spares.sch]
2017-09-20 Change 33pf to 100pf. Change 2k and 2200 to 2k2. Change I2C addresses for MCP23008. Nudge link connectors
    [PiPtr.kicad_pcb, PiPtr.sch, audioChannel.sch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]
2017-09-20 Change 90k to 88k7 and 50k to 51k
    [PiPtr.kicad_pcb, PiPtr.sch, audioChannel.sch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]
2017-09-25 Add files via upload
    Fix i2c addressing
    Change footprint for LDR
    Move connectors for temp/hum sensor and rtc so they won't hit the Pi
    [PiPtr.kicad_pcb, PiPtr.sch, audioChannel.sch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]
2017-09-25 Add LDR footprint
2017-09-29 Add Digikey part # to all parts. Fix unconnected nets
    [PiPtr.kicad_pcb, PiPtr.sch, audioChannel.sch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]
2017-10-06 intital hardware changes for new schematic and user IO setup
2017-10-25 Add SeeedStudio footprints
2017-10-25 Switch to 0402 parts and SeeedStudio footprints
    Silk screen is still being updated. BOM needs to be updated as well
    [PiPtr.kicad_pcb, PiPtr.sch, audioChannel.sch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]
2017-10-30 initial PCB order at seeed
    [PiPtr-B.Cu.gbl, PiPtr-B.Mask.gbs, PiPtr-B.Paste.gbp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]
2017-11-04 Version with updated silkscreen
    [PiPtr.kicad_pcb]
2017-11-07 version for initial fab
    [PiPtr-B.Cu.gbl, PiPtr-B.Mask.gbs, PiPtr-B.Paste.gbp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]
2017-11-10 interrupt and hwio debug
2017-12-17 working pwm functions
2017-12-20 port detection and TH sensor
2017-12-20 debug DHT sensor
2017-12-20 debug audio switches
2017-12-28 fix link tx audio
    [fpPixels.py, gui.py, main.py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]
2017-12-29 threading debug and cleanup
2017-12-29 initial cut at setup script
2018-01-06 clean up port detcion errors
    [hwio.py]
2018-02-09 set spi speed for ADC to under 3.6Mhz
2018-02-09 adjust spi timing
2018-08-18 Switched to espeak-ng and new vioce
2020-01-05 added pl board control
2020-02-09 I2C 0 testing
2020-02-25 correct a few typos
    [hwio.py]
